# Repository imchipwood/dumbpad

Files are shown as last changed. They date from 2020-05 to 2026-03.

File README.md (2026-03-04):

 <a href="http://www.amitmerchant.com/electron-markdownify">dumbpad logo</a>

dumbpad is a simple macropad with support for up to two rotary encoders, designed to use [QMK](https://qmk.fm/) firmware.

## Gallery

v0.2 and v0.7 revisions in various layouts

Top two boards are v0.2, bottom two are v0.7. Bottom right is v0.7 with components soldered to the bottom, moving the rotary encoder to the right side.

## In this repository

This repo is separated into five main folders:

- [combo](./combo) houses the main PCB design which includes support for up to two rotary encoders and three status LEDs intended for the Pro Micro.
- [combo_oled](./combo_oled) was created by [KEEBD](https://keebd.com) and replaces the layer LED/Resistors with OLED display support and converted to KiCad.
- [combo_oled_low_profile](./combo_low_profile_oled) Revision of [combo_oled](./combo_oled) with low profile hot swap sockets for Gateron v2 switches
- [combo_teensy](./combo_teensy) is the same as [combo](./combo) but designed for the Teensy2.0.
- [reversible](./reversible) is an older, single-encoder revision using custom reversible Cherry MX sockets to allow the rotary encoder to be moved to the right side.
- [hotswap_rgb - v3.x](./hotswap_rgb) dumbpad featuring per-key RGB and Hotswap sockets

Each folder includes the Eagle or KiCad files as well as exported Gerber files for manufacturing. These folders also include readmes specific to those designs - check them for more info.

## Getting Started
To build your own dumbpad you will need to follow a couple of steps to get started. Described below are the minimal steps you will need to take to to assemble one dumbpad but every board configuration might require different steps. 
#### 1. Choose version. 
You can choose from one of the five different versions shown in the step above.
#### 2. Order your parts. 
Every board needs at least the following components but check the right folder for your parts list.
* 1 x PCB
* 16 x MX-style mechanical switches
* 17 x 1n4148 diodes (thru hole)
* 1 x Arduino Pro Micro or pin-compatible ATmega32u4-based MCU (Or teensy for the teensy version)
* (optional) 1 x EC11 rotary encoder with pushbutton (7-pin)
* (optional) 1 x 6mm tactile switch (to reset MCU)
* LEDS and OLED required for different configurations

#### 3. Assemble your dumbpad
For this step you will need a minimum of a soldering iron and a pair of tweezers
- Solder the diodes, switches, and Arduino Pro Micro (Or teensy) to the PCB

#### 4. Flash your firmware
You can use QMK to create and flash firmware to your dumbpad. You can configure every key to you can use the QMK configurator. Head over to the [QMK configurator](https://config.qmk.fm/#/friedrich/LAYOUT) and select dumbpad/[your version]. Once you have configured your board, click on compile and then on firmware to download the firmware. Check [qmk_firmware/keyboards/dumbpad](https://github.com/qmk/qmk_firmware/tree/master/keyboards/dumbpad) for compiling & uploading instructions

Once you have downloaded a .HEX firmware file we can head over to the [QMK toolbox](https://github.com/qmk/qmk_toolbox/releases) and flash the firmware. Plug in your dumbpad to your computer and set your QMK toolbox to ATmega32U4 for most Arduino Pro Micros. You will need to press your 6mm tacticle switch twice to enter the bootloader, wait for your computer to reconize the dumbpad and click on flash.

### Features

#### Status Indicator LEDs

All PCB revisions in this branch support up to three LEDs.

| LED position on PCB | LED name in QMK software | LED default behavior |
|:-:|:-:|:-:|
| right | LED_00 | 1s bit in binary layer indication |
| center | LED_01 | 2s bit in binary layer indication |
| left | LED_02 | numlock indicator |

LED_00 (right) and LED_01 (center) indicate the layer by displaying the layer number in binary:

| center LED | right LED  | layer |
|:---:|:---:|:---:|
| off | off | 0 (main) |
| off |  on | 1 |
|  on | off | 2 |
|  on |  on | 3 |

LED behavior can be changed in the QMK software if you'd like them to do something else. See [v1x.c](https://github.com/imchipwood/qmk_firmware/blob/dumbpad_refactor/keyboards/dumbpad/v1x/v1x.c) for reference.

#### (Optional) Reset Button

[combo](./combo), [hotswap_rgb](./hotswap_rgb) and [reversible](./reversible) have a 6mm switch socket that is optional to include when building your dumbpad. This socket shorts RST to GND to make it easy to enter the bootloader. This is not included in the [combo_teensy](./combo_teensy) design as the Teensy has a reset button already.

If you don't want to solder this switch, make sure to include the [RESET](https://docs.qmk.fm/#/quantum_keycodes) keycode somewhere in your keymap. If you don't include this keycode, you can still enter the bootloader by shorting RST to GND while plugging in the USB cable.

## PCB Dimensions and Cases

97mm x 78.5mm rectangle, with chamfered corners (chamfered edge is 2.828mm long).

There are several cases available for printing, some can be found in `./case`. Another nice case was designed by [f00k3r](https://twitter.com/f00k3r) and uploadead to printables: [Dumbpad Hotswap Case](https://www.printables.com/model/200528-dumbpad-hotswap-case).

### Mounting holes

There are four 2mm holes in a 40mm square centered at (x, y) 58.575mm, 39.425mm. These holes are not plated.

Mounting hole coordinates:

| x (mm) | y (mm) |
|:---:|:---:|
| 38.575 | 19.425 |
| 38.575 | 59.425 |
| 78.575 | 19.425 |
| 78.575 | 59.425 |

## Notes

- In particular, clickable rotary encoders take significantly more force to click than a keyboard switch, so place a rubber foot directly under or at least near any encoders

## Making the PCB

Every parts list includes at least one PCB. You can order a PCb yourself by different manufactures like; [PCB way](https://www.pcbway.com/) or [JLC Pcb](https://jlcpcb.com/) Submit one of the gerber zips from the folder of the type of board you want to make to your preferred manufacturer (or the Eagle .brd file if supported).

render of boards

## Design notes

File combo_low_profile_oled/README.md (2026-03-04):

# dumbpad - Low Profile OLED (aka v1.3)

Modified by [ReyvanZA]

## Description

Version of the original dumbpad but with support for an OLED display by Keebd, now with gateron low profile hot swap sockets.
There are also mounting points for a uController cover, and through holes for wires if using a ProMicro nrf52840 for the battery wires (admittedly not overly practical).

Only 1.3.1 has been tested with the gateron low profile hot-swap sockets. The gerber files included (see manufacturing notes at the end)

### Revisions

- 1.2 Keebd OLED with resistors
- 1.3.1 Gateron low profile hot-swap sockets (Confirmed working - need low profile keys to test)
- 1.3.2 (Untested) Combined plated though holes for EC11 rotary encoder mounting points and socket, added mounting holes for uController cover. Placed resistors on back of PCB so I can use an alignment plate for the switches to hold them more steadily.

### References

- Gateron low profile hot-swap sockets: https://gist.github.com/niw/22c68c2d7c869b990588b4875a654442

#### dumbpad v1.3.1

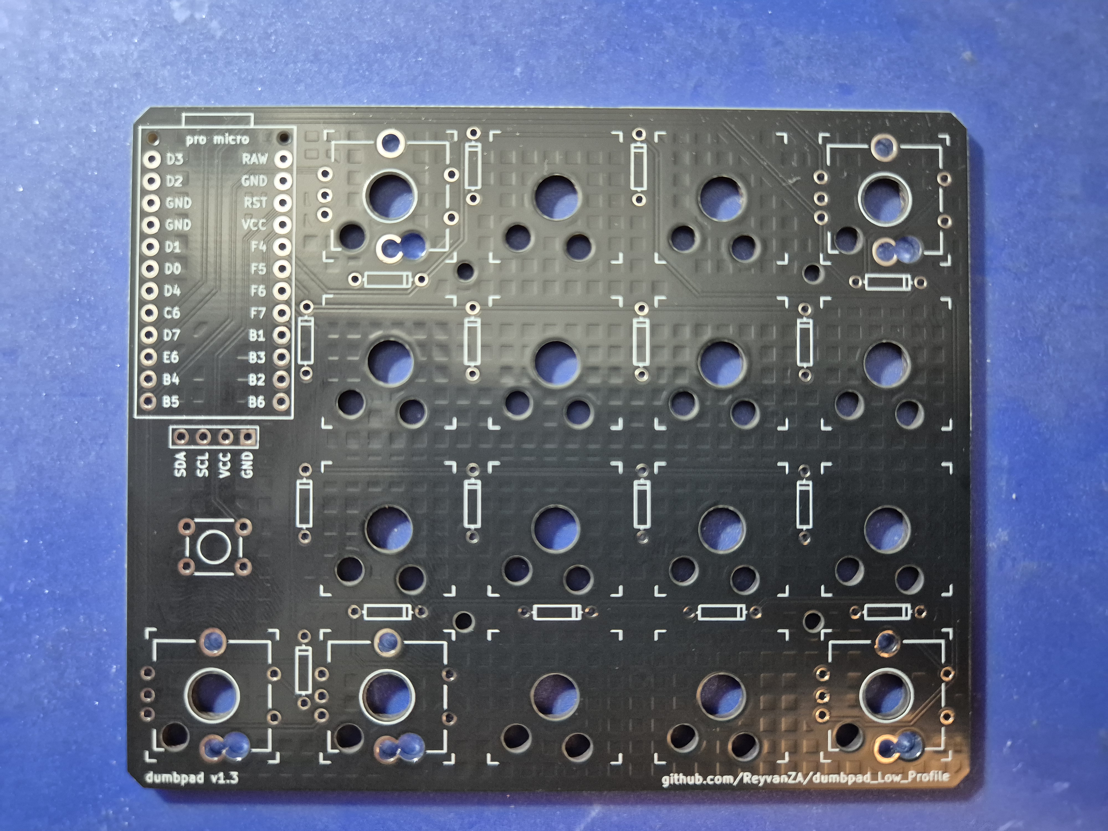
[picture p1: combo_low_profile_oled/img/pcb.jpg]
pcbs

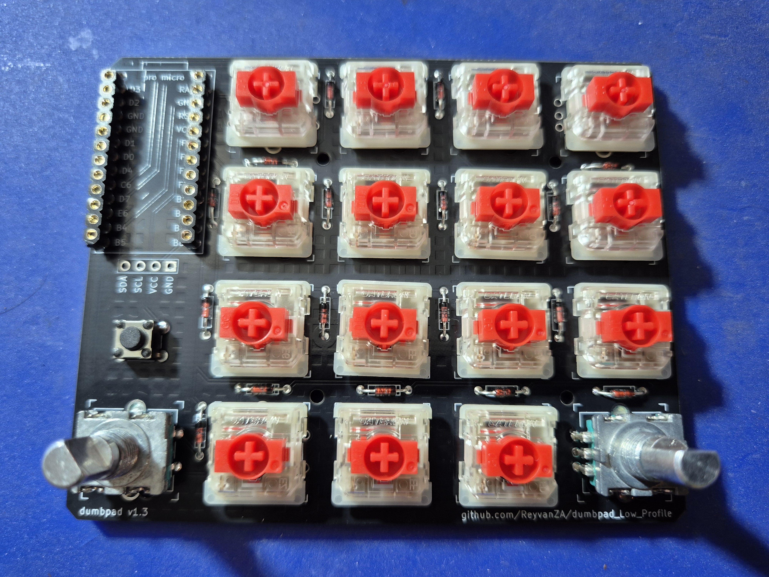
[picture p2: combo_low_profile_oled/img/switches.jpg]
finished

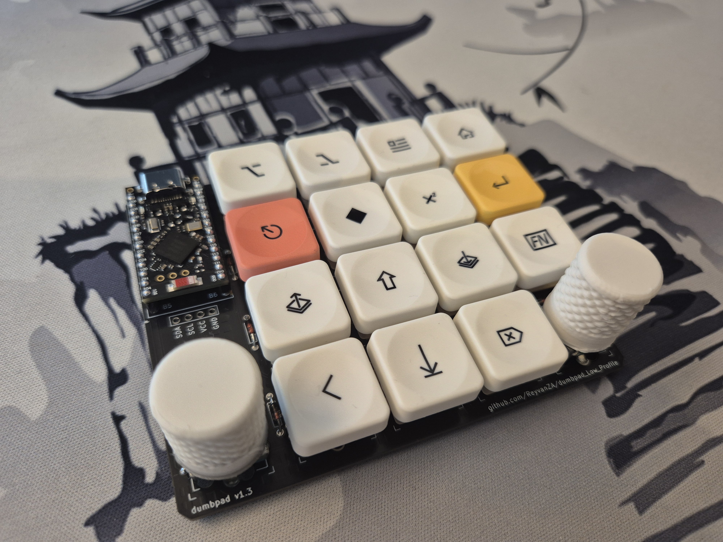
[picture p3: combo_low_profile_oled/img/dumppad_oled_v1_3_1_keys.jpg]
Keys1

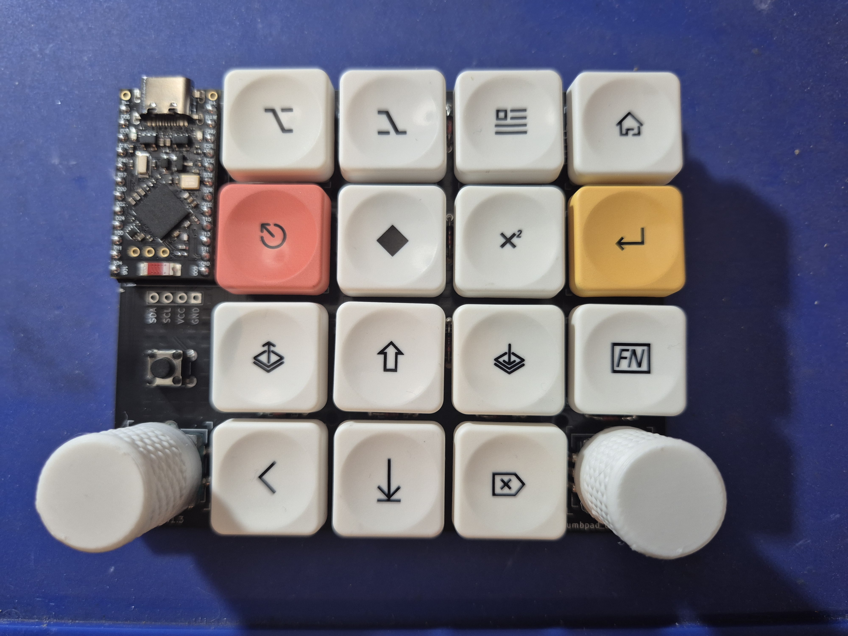
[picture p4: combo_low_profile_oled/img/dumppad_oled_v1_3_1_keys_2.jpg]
keys2


#### Renders (Latest Revision)

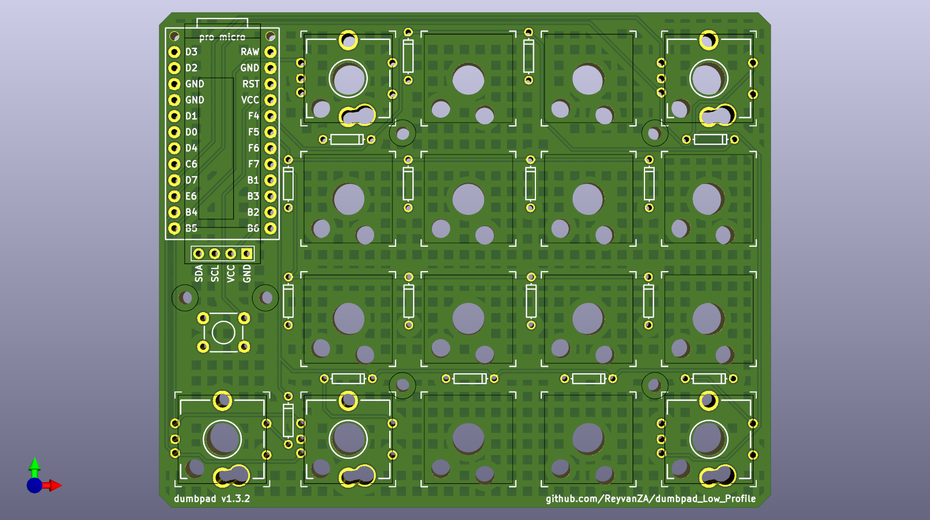
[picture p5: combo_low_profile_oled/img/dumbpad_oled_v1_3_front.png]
front

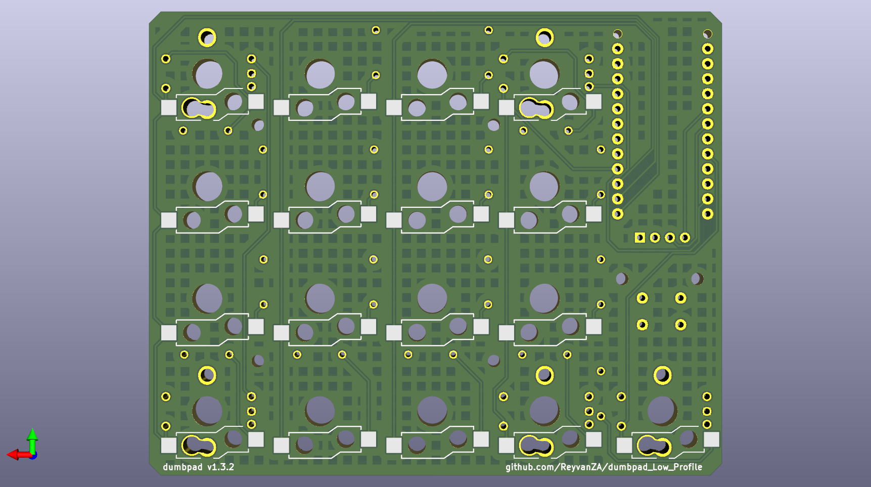
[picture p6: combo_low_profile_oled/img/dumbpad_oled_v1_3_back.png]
back


### Bill of materials
- 1 x PCB
- 16 x Gateron low profile switches (Link)
- 16 x Gateron low profile hot-swap sockets (Link)
- X x Keycaps (compatible with Gateron low profile switches)
- 17 x 1n4148 diodes (thru hole)
- 1 x Arduino Pro Micro or pin-compatible ATmega32u4-based MCU (Or teensy for the teensy version)
- 1 x or 2x EC11 rotary encoder with pushbutton (7-pin)
- 1 x 6mm tactile switch (to reset MCU)
- 1 x 0.91" 128X32 OLED Display (Optional)

## OLED Firmware

The OLED firmware is different and can be found here [Firmware](https://docs.keebd.com/firmware/)

## How to build 
- Be very careful when soldering pads next to rotary encoder through holes (encoder pin b), you may get bridging.
- I've moved the pin slightly closer to the ground pin to aleviate this issue. This does not affect assembly.

You can follow the instructions from the main [readme](https://github.com/imchipwood/dumbpad#getting-started) or follow the instruction in this [blog](https://www.timowielink.com/post/how-to-build-a-macropad) from [Timo Wielink](https://github.com/TimoWielink)

When the 1.3.1 production file is created by your PCB manufacturer, you may have a query on the overlapping through holes. If given the option allow them to plate both holes.

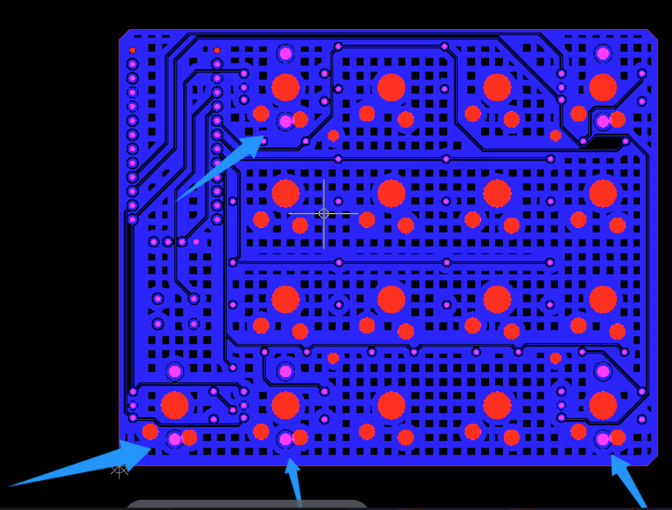
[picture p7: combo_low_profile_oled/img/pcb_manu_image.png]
Manufacturer


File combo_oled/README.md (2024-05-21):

# dumbpad - OLED (aka v1.2)

Designed by [KEEBD](https://www.keebd.com).

## Description

Version of the original dumbpad but with support for an OLED display in place of the LED's and resistors.
The EC11 rotary encoder-compatible slots have a non-plated through-punch for their mounting point on each side, which may be flagged as erronious by PCB manufacturers but has no effect on functionality.

### Revisions

- 1.2 Initial published PCB

#### dumbpad v1.2

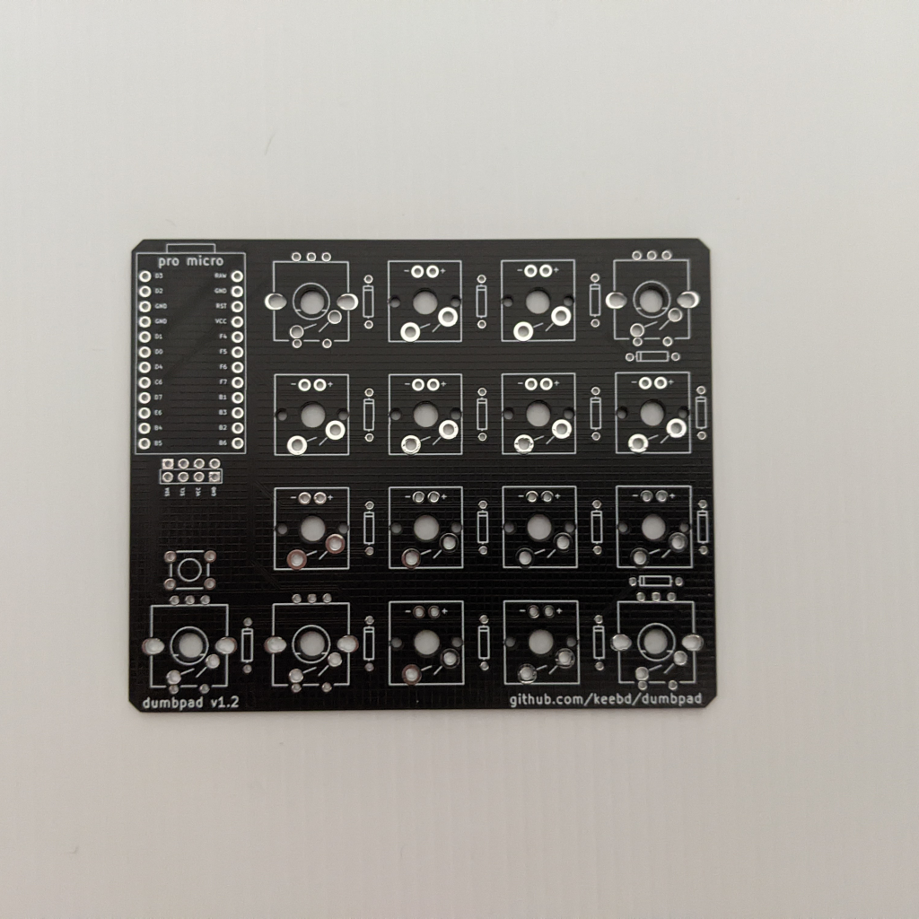
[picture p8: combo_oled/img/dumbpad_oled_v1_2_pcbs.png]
pcbs

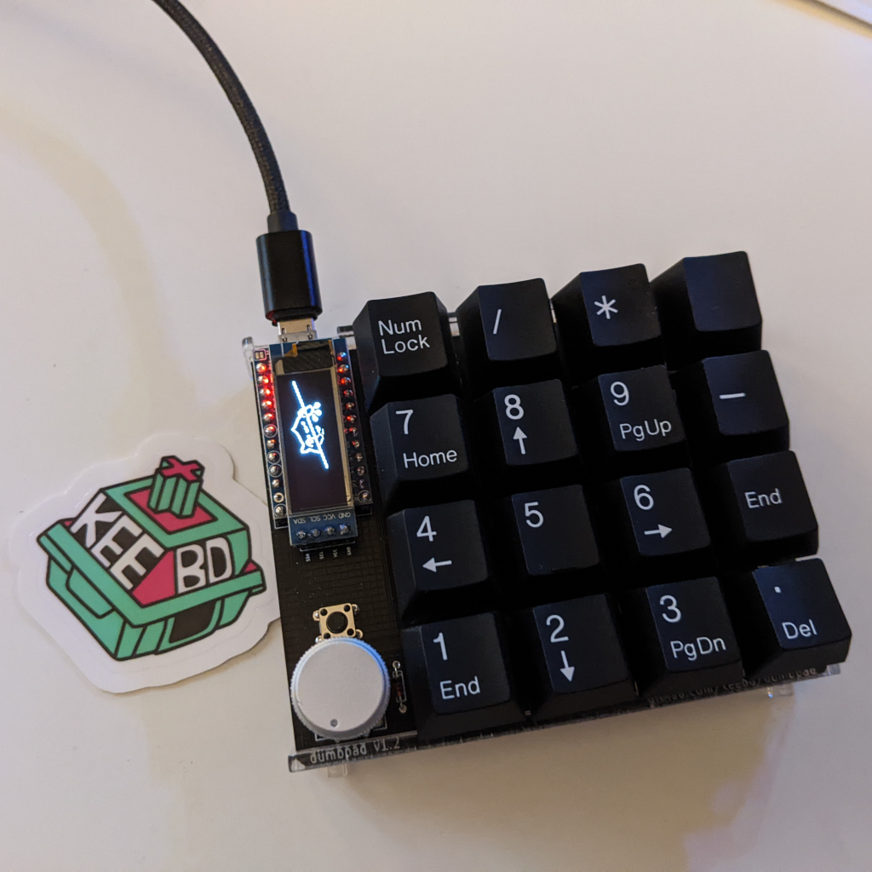
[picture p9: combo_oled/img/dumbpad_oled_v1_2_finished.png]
finished


#### Renders

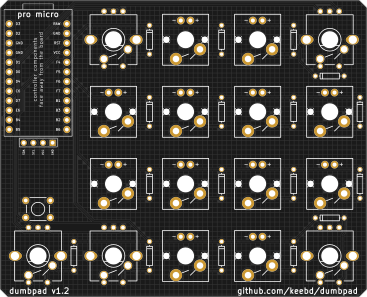
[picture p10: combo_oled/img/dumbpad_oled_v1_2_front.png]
front

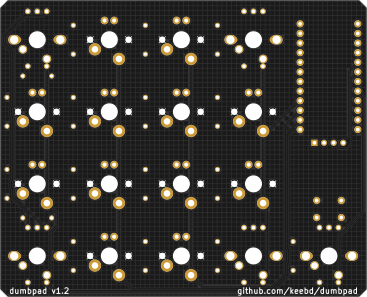
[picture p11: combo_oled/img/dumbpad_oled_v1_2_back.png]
back


### Bill of materials
- 1 x PCB
- 16 x MX-style mechanical switches
- 17 x 1n4148 diodes (thru hole)
- 1 x Arduino Pro Micro or pin-compatible ATmega32u4-based MCU (Or teensy for the teensy version)
- 1 x or 2x EC11 rotary encoder with pushbutton (7-pin)
- 1 x 6mm tactile switch (to reset MCU)
- 1 x 0.91" 128X32 OLED Display

## OLED Firmware

The OLED firmware is different and can be found here [Firmware](https://docs.keebd.com/firmware/)

## How to build 
You can follow the instreuctions from the main [readme](https://github.com/imchipwood/dumbpad#getting-started) or follow the instructiosn in this [blog](https://www.timowielink.com/post/how-to-build-a-macropad) from [Timo Wielink](https://github.com/TimoWielink)

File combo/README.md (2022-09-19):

# dumbpad/combo

This folder houses the dumbpad "combo" design - this layout uses custom "combo" Cherry MX + EC11 rotary encoder sockets that allow a single PCB design to support both single- and dual-encoder layouts.

## Compiling QMK

The [QMK Configurator](https://config.qmk.fm/#/dumbpad/v1x/LAYOUT) can compile the various dumbpad versions
with basic rotary encoder support. The default rotary encoder actions are as follows:

| Layer | Clockwise | Counter-clockwise |
|:-:|:-:|:-:|
| 1 | KC_MS_R (move mouse right) | KC_MS_L (move mouse left) |
| 2 | KC_EQUALS (Adobe "increase") | KC_MINUS (Adobe "decrease") |

If you want the encoder to do something else, you will need to clone the [qmk_firmare](https://github.com/qmk/qmk_firmware) repository and modify the rotary encoder code. The [QMK docs](https://docs.qmk.fm/#/newbs) can help you with this.

## Eagle PCB render

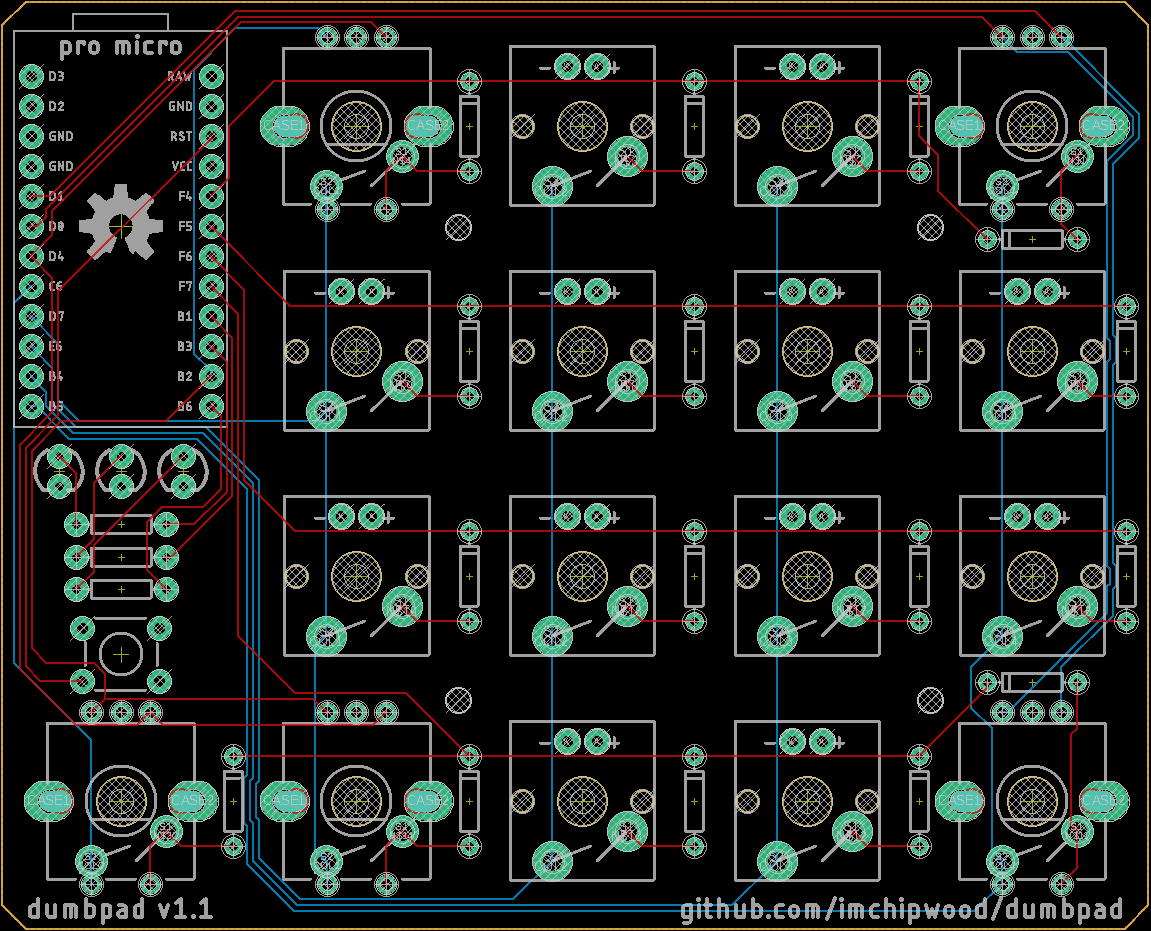
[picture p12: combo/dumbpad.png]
dumbpad


## Case

A case is available on [Thingiverse](https://www.thingiverse.com/thing:4816409) - thanks to Anthony @ [customkbd.com](http://customkbd.com.au/) for the initial design and being kind enough to send the original design files!

## Single- vs Dual-Encoder Support

The combined Cherry MX/encoder sockets allow single- and dual-encoder configurations.

The only rule when using two encoders is that there cannot be two encoders on the left side at once, or two on the right side.
This table shows where the encoders are in the switch grid ("X" for encoder, "s" for switch):

| C0  | C1  | C2  | C3  | C4  |
|:---:|:---:|:---:|:---:|:---:|
| |__X__|  s  |  s  |__X__|
| |  s  |  s  |  s  |  s  |
| |  s  |  s  |  s  |  s  |
|__X__|__X__|  s  |  s  |__X__|

- The three encoders in columns C0 and C1 are connected to each other
- The two encoders in column C4 are connected to each other

So, if doing dual encoders, one must be in column C4 and the other in either C0 or C1. Three or more encoders will not work.

The following sections describe the configurations that the default keymaps in QMK are designed for.

### Single-Encoder (Default Configuration)

In the default configuration, the encoder is in column 0, the bottom left corner below the Pro Micro. All other sockets are filled with switches.

| C0  | C1  | C2  | C3  | C4  |
|:---:|:---:|:---:|:---:|:---:|
| |  s  |  s  |  s  |  s  |
| |  s  |  s  |  s  |  s  |
| |  s  |  s  |  s  |  s  |
|__X__|  s  |  s  |  s  |  s  |

single encoder

### Dual-Encoder Bottom

One dual-encoder configuration has encoders in the bottom two corners of the 4x4 grid, and switches in the rest of the grid. The socket in column 0 is left empty.

| C0  | C1  | C2  | C3  | C4  |
|:---:|:---:|:---:|:---:|:---:|
| |  s  |  s  |  s  |  s  |
| |  s  |  s  |  s  |  s  |
| |  s  |  s  |  s  |  s  |
| |__X__|  s  |  s  |__X__|

dual-encoder bottom

### Dual-Encoder Top

Another dual-encoder configuration has encoders in the top two corners of the 4x4 grid, and switches in the rest of the grid. The socket in column 0 is left empty.

| C0  | C1  | C2  | C3  | C4  |
|:---:|:---:|:---:|:---:|:---:|
| |__X__|  s  |  s  |__X__|
| |  s  |  s  |  s  |  s  |
| |  s  |  s  |  s  |  s  |
| |  s  |  s  |  s  |  s  |

dual-encoder top

### No-Encoder

You may also choose not to use any rotary encoders if you like!

### Bill Of Materials

- 1 x PCB
- 16 x MX-style mechanical switches
- 17 x 1n4148 diodes (thru hole)
- 1 x Arduino Pro Micro or pin-compatible ATmega32u4-based MCU (Or teensy for the teensy version)
- 1x or 2x EC11 rotary encoder with pushbutton (7-pin)
- (optional) 1 x 6mm tactile switch (to reset MCU)
- (optional) 3x 3mm resistors (for limiting current in LEDs)

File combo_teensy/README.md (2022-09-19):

# dumbpad/combo_teensy

This folder houses the dumbpad "combo_teensy" design - this layout uses custom "combo" Cherry MX + EC11 rotary encoder sockets that allow a single PCB design to support both single- and dual-encoder layouts. It uses Teensy2.0 microcontroller instead of a Pro Micro

## Eagle PCB render

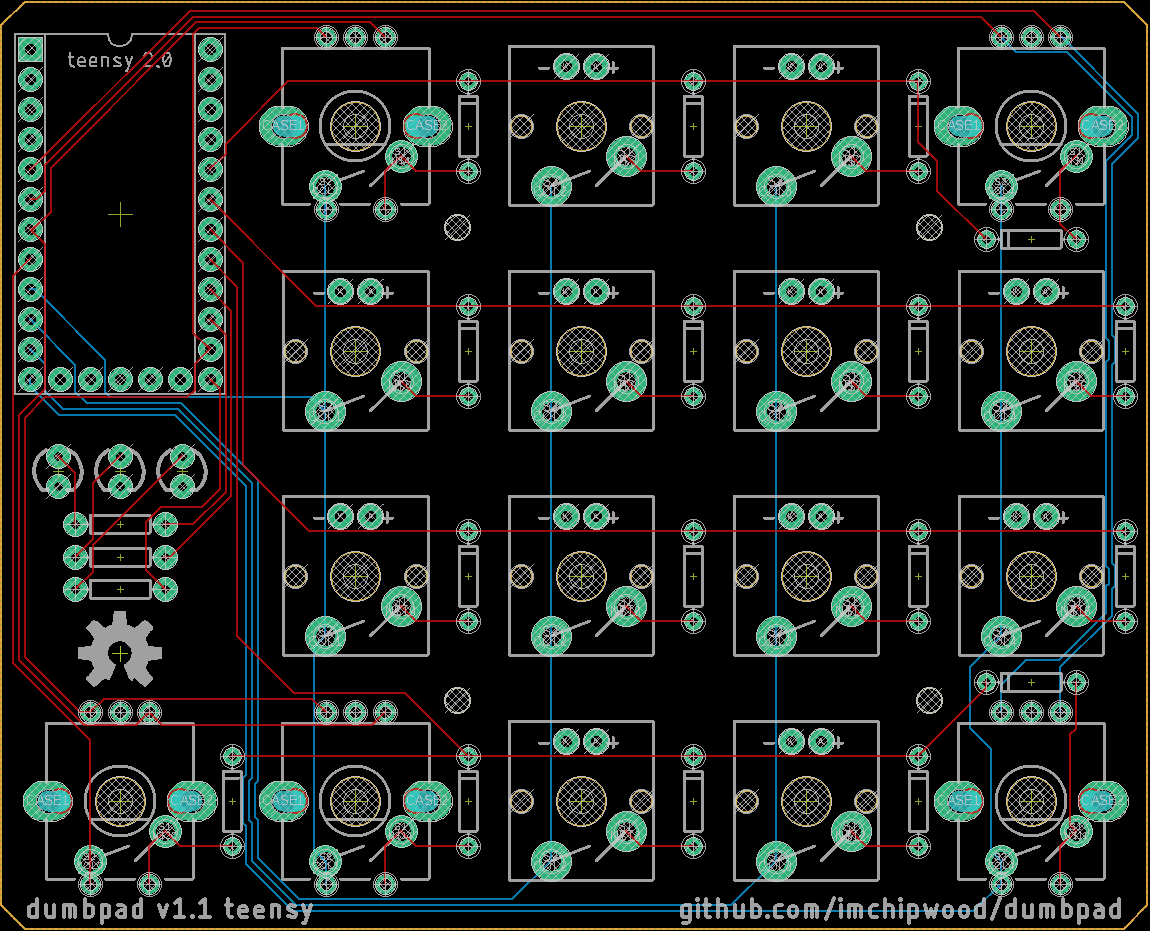
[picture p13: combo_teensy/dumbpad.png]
dumbpad


## Single- vs Dual-Encoder Support

The combined Cherry MX/encoder sockets allow single- and dual-encoder configurations.

The only rule when using two encoders is that there cannot be two encoders on the left side at once, or two on the right side.
This table shows where the encoders are in the switch grid ("X" for encoder, "s" for switch):

| C0  | C1  | C2  | C3  | C4  |
|:---:|:---:|:---:|:---:|:---:|
| |__X__|  s  |  s  |__X__|
| |  s  |  s  |  s  |  s  |
| |  s  |  s  |  s  |  s  |
|__X__|__X__|  s  |  s  |__X__|

- The three encoders in columns C0 and C1 are connected to each other
- The two encoders in column C4 are connected to each other

So, if doing dual encoders, one must be in column C4 and the other in either C0 or C1. Three or more encoders will not work.

The following sections describe the configurations that the default keymaps in QMK are designed for.

### Single-Encoder (Default Configuration)

In the default configuration, the encoder is in column 0, the bottom left corner below the Pro Micro. All other sockets are filled with switches.

| C0  | C1  | C2  | C3  | C4  |
|:---:|:---:|:---:|:---:|:---:|
| |  s  |  s  |  s  |  s  |
| |  s  |  s  |  s  |  s  |
| |  s  |  s  |  s  |  s  |
|__X__|  s  |  s  |  s  |  s  |

### Dual-Encoder Bottom

One dual-encoder configuration has encoders in the bottom two corners of the 4x4 grid, and switches in the rest of the grid. The socket in column 0 is left empty.

| C0  | C1  | C2  | C3  | C4  |
|:---:|:---:|:---:|:---:|:---:|
| |  s  |  s  |  s  |  s  |
| |  s  |  s  |  s  |  s  |
| |  s  |  s  |  s  |  s  |
| |__X__|  s  |  s  |__X__|

### Dual-Encoder Top

Another dual-encoder configuration has encoders in the top two corners of the 4x4 grid, and switches in the rest of the grid. The socket in column 0 is left empty.

| C0  | C1  | C2  | C3  | C4  |
|:---:|:---:|:---:|:---:|:---:|
| |__X__|  s  |  s  |__X__|
| |  s  |  s  |  s  |  s  |
| |  s  |  s  |  s  |  s  |
| |  s  |  s  |  s  |  s  |

### No-Encoder

You may also choose not to use any rotary encoders if you like!

### Bill Of Materials

1 x PCB
16 x MX-style mechanical switches
17 x 1n4148 diodes (thru hole)
1 x Teensy2.0 
1 x or 2 x EC11 rotary encoder with pushbutton (7-pin)
- (optional) 3x 3mm LEDs
- (optional) 3x 3mm resistors (for limiting current in LEDs)
- (optional) 6mm SPST switch for resetting MCU

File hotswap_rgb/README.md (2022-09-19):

# dumbpad - Hotswap - RGB (aka v3x)

Designed by [deveth0](https://www.github.com/deveth0).

## Description

Version of the original dumbpad that features Kailh Hotswap Sockets and (optional) RGB per-key lightning.

### Revisions

- 3.1 Initial published PCB

#### dumbpad v3.1

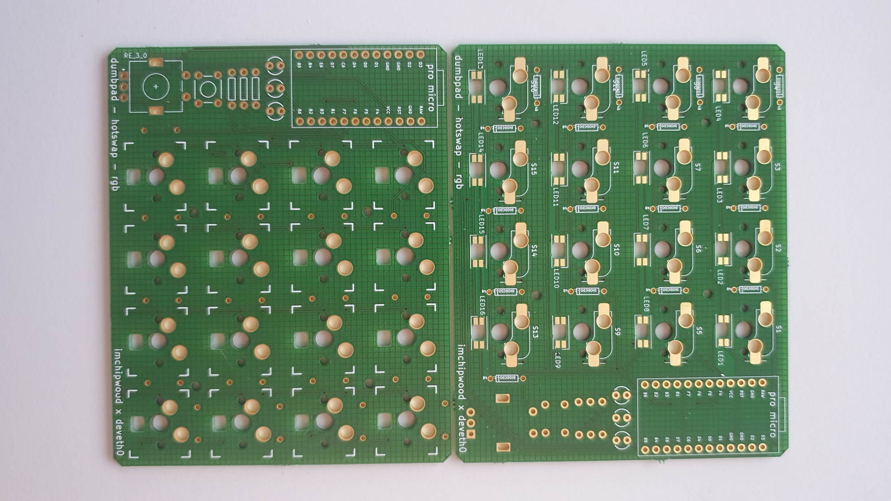
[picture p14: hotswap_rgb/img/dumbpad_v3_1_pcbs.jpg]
pcbs

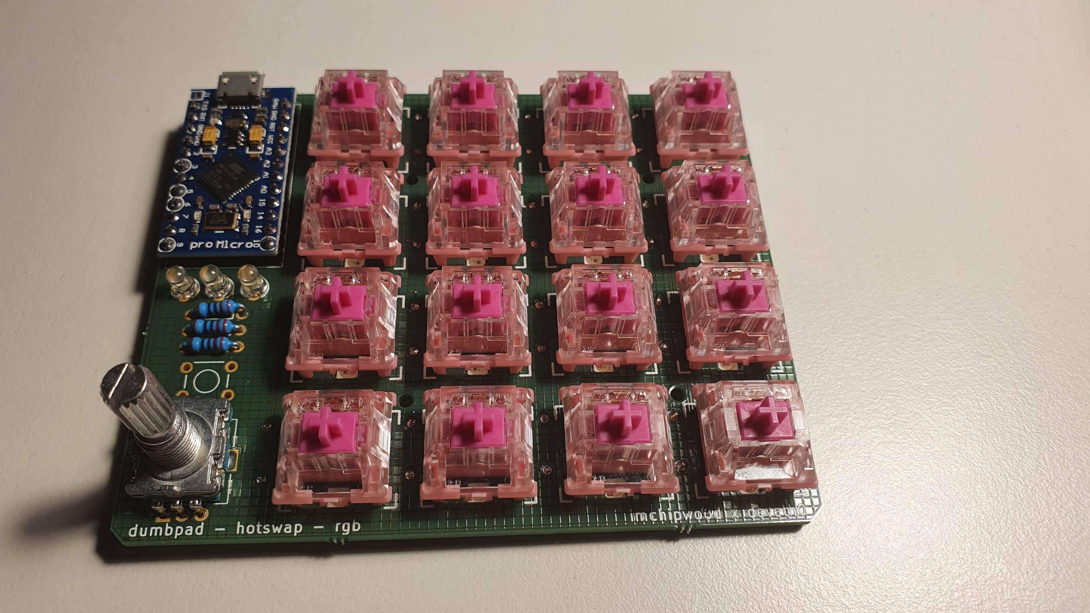
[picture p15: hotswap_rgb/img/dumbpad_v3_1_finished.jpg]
finished


#### Renders
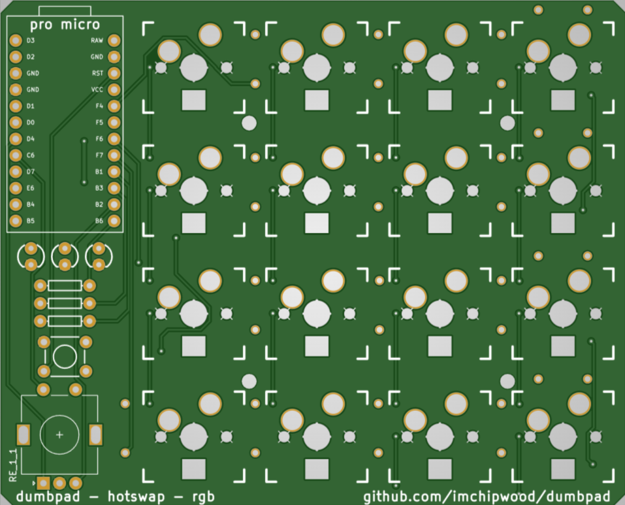
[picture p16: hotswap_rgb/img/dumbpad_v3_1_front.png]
front


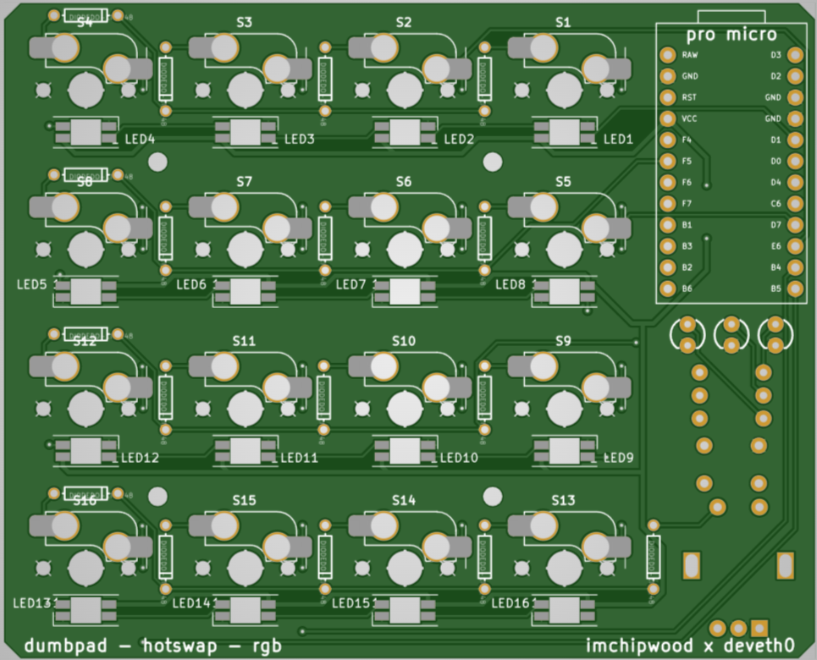
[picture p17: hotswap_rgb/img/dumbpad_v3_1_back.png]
back


### Bill of materials

* 16x Kailh Hotswap Sockets (rev 2)
* 16x Cherry-style mechanical switches
* 17x 1n4148 diodes (thru hole)
* 1x Arduino Pro Micro or pin-compatible ATmega32u4-based MCU
* 1x EC11 rotary encoder with pushbutton (7-pin)
* (optional) 16x SK6812 mini e LEDs
* (optional) 1x 6mm tactile switch (to reset MCU)
* (optional) 3x 3mm LEDs (whatever color)
* (optional) 3x 330ohm or similar resistors for the LEDS (not needed if not adding LEDs)

## Making the PCB

Submit either the KiCad `.kicad_pcb` or the gerber files to your prefered PCB manufacturer.

### Notes on soldering

It's recommended to start with the Sockets and then add the remaining parts.

Solder the SK6812 LEDs with the missing corners aligned with the corners printed on the PCB as shown in the image.

*NOTE:* the orientation of the LEDs changes between the lines!

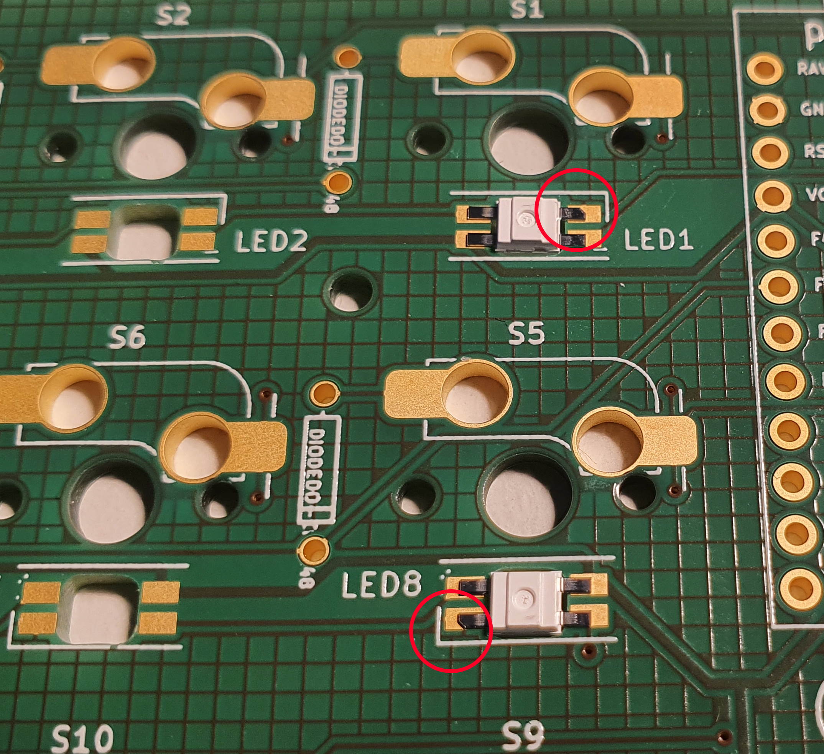
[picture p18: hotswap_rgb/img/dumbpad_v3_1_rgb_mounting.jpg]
rgb


## Acknowledgements

Some of the footprints are extracted from the awesome [Corne Keyboard](https://github.com/foostan/crkbd) by [Kosuke Adachi](https://github.com/foostan).

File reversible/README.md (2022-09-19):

# dumbpad
Designed by [imchipwood](https://www.github.com/imchipwood) in Portland, Oregon, USA

Special thanks to [QMK](https://qmk.fm/) for open-source keyboard firmware

## Description
dumbpad is a simple 4x4 numpad with a rotary encoder. It is designed for the ATmega32u4-based Pro Micro but any ATmega32u4-based microcontroller using the same form factor should work

It is designed to run [QMK firmware](https://github.com/qmk/qmk_firmware) - check [qmk_firmware/keyboards/dumbpad](https://github.com/qmk/qmk_firmware/tree/master/keyboards/dumbpad) for compiling & uploading instructions

### Revisions
- v0.5 introduces 2x LEDs for indicating which layer is enabled, accurately representing up to 4 layers
- v0.6_dualencoder is a true 4x4 macropad with two rotary encoders - one in each bottom corner
- v0.6_dualencoder_top is the same as v0.6_dualencoder but the encoders are moved to the top corners
- v0.7 PCB is flippable. Two jumpers must be soldered:
  - Encoder on left (default layout) - solder the left side of the jumpers to the center
  - Encoder on right (PCB upside down) - solder the right side of the jumpers to the center
- v1.0 PCB adds a 3rd LED - default use is to indicate if NUMLOCK is on

#### dumbpad v0.2 (top) & v0.7 (bottom), PCB by [OSH Park](https://www.oshpark.com)
dumbpad
#### Dual-encoder version by chicocode:
dumbpad
#### Eagle PCB render
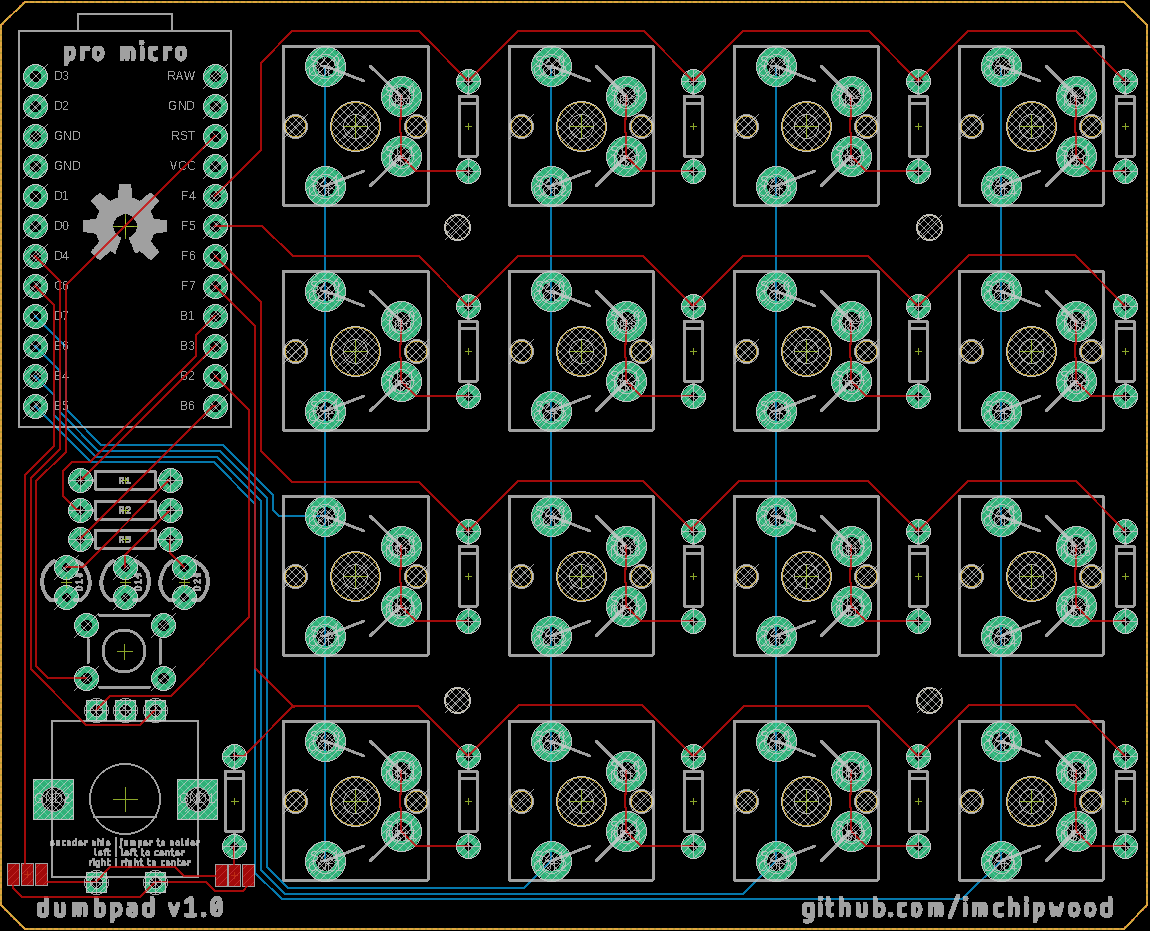
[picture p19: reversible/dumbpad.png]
dumbpad


### Bill of materials
* 16x Cherry-style mechanical switches
* 17x 1n4148 diodes (thru hole)
* 1x Arduino Pro Micro or pin-compatible ATmega32u4-based MCU
* 1x EC11 rotary encoder with pushbutton (7-pin)
* (optional) 1x 6mm tactile switch (to reset MCU)
* (optional) 3x 3mm LEDs (whatever color)
* (optional) 3x 330ohm or similar resistors for the LEDS (not needed if not adding LEDs)

#### Notes
- No case is currently available, but v1.0 has 2mm mounting holes in a 40mm square centered at x=58.575mm, y=39.425mm (from the bottom left)
  - 38.575, 19.425
  - 38.575, 59.425
  - 78.575, 19.425
  - 78.575, 59.425
- To avoid damaging the PCB and prevent it from sliding around, put rubber feet on the bottom of the PCB
  - place feet directly under the rotary encoder(s) as they take significant force to press
  - place the others in the corners and one in the center

## Making the PCB
Submit the `.brd` file to your preferred PCB manufacturer - be mindful of minimum quantity requirements.

### OSH Park - USA PCB Manufacturing
Shameless Portland, Oregon company plug - [OSH Park](https://www.oshpark.com) is a fast and reliable manufacturer, combining multiple individual orders into a single panel to minimize end-user costs. dumbpad is just under $60 for 3 copies through OSH Park.

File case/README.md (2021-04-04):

# Dumbpad Case

based off the original design by Anthony @ [customkbd.com.au](https://customkbd.com/collections/cases/products/dumbpad-3d-printed-highcase) - huge thanks to him for his initial work and sending me the STL files I used to create a batch through Shapeways

Files also available on [Thingiverse](https://www.thingiverse.com/thing:4816442)

## Changes from Anthony's design

Main difference is some tabs added in the corners to support the PCB a little better.

I found the original design flexed quite a bit, especially when pressing the rotary encoder. This design aims to fix that.

Also removed some material under the Pro Micro USB port to prevent stress on the port if the Pro Micro is soldered directly to the PCB.

## Redesigned using SketchUp because

1. I suck at any other 3d modeling software
1. I've used it before
1. It was literally quicker to redraw the whole thing in SketchUp than try to learn a new tool.

### dumbpad_case

Basic case.

### dumbpad_case_emboss

Same as dumbpad_case with "dumbpad" emboss on the rear face.

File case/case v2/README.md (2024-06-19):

# Printing Settings:
I use a Flying Bear Ghost 5 with a 0.4mm nozzle.

## File: dumbpad_lid.stl
Horizontal Hole Expansion:
Adjust the horizontal hole expansion parameter in Cura or a similar slicer. Recommended values range from -1.6 to -0.2.
## File: 6mm_split_shaft_pot_knob_12mm.stl
Horizontal Hole Expansion:
The required adjustment depends on the type of filament used to ensure a snug fit of the knob on the shaft without wobbling. Alternatively, a 6mm drill bit can be used for precise fitting.
## Mounting the PCB:
 Use 4 M2x5mm bolts to secure the PCB to the case. Alternatively, other bolt sizes can be used by adjusting the horizontal hole expansion settings accordingly.
## Additional Information
 All files were edited using KOMPAS-3D software, and the source files in .m3d format are also included.

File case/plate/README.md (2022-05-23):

## 3D-Printable Mounting Plate for dumbpad
Mounting plates designed for dumbpad v1.x ([dumbpad by imchipwood](https://github.com/imchipwood/dumbpad/)); fits in the case designed by Anthony @ [customkbd.com.au](https://customkbd.com.au/); 1.5mm thick.

I found out that the hot-swap sockets I soldered in cannot hold switches firmly enough, and plates were needed. Hence, I started this project.

Also available on [Thingiverse](https://www.thingiverse.com/thing:4971965)
<br/><br/>

### COMBOS
- 2 Rotary Encoders
  - [2 rotary encoders on top](2_top.stl)
  - [2 rotary encoders on bottom](2_bot.stl)
- 1 Rotary Encoders
  - [top left](top_left.stl)
  - [top right](top_right.stl)
  - [bot left](bot_left.stl)
  - [bot right](bot_right.stl)
- No Rotary Encoders/Default
  - [full plate](full_plate.stl)

*Note: The thinnest edge is the right edge, otherwise it won't fit into the case*

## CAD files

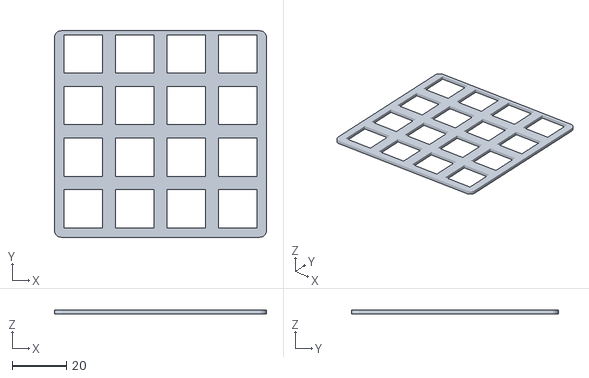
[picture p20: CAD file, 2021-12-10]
case/plate/full_plate.stl
78.4 x 76.4 x 1.50

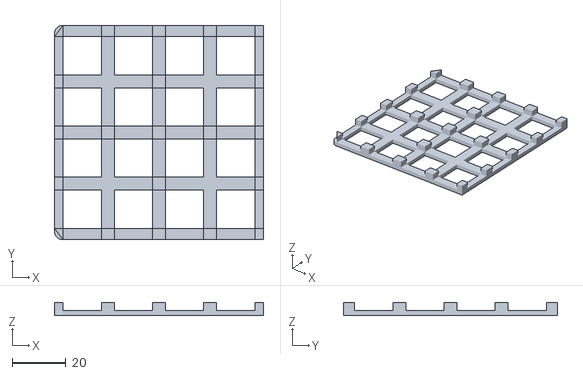
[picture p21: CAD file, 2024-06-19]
case/case v2/dumb_pleyt_v2.stl
77.8 x 79.8 x 5.00

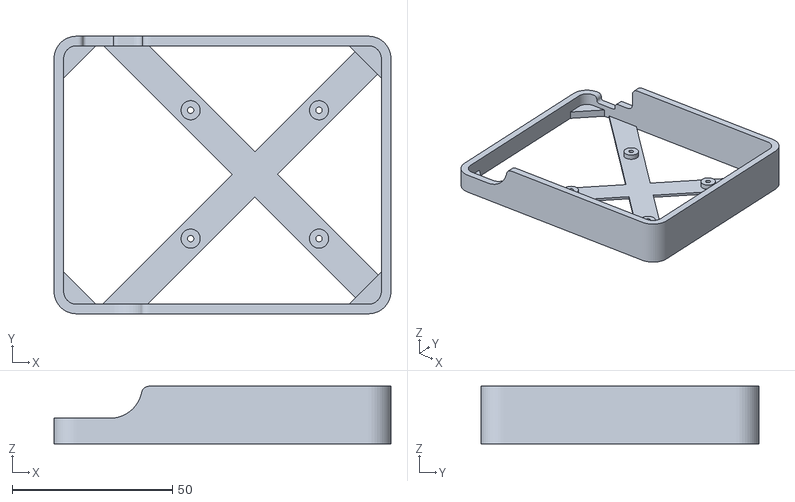
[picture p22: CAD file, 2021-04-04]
case/dumbpad_case.stl
105.0 x 86.5 x 18.0

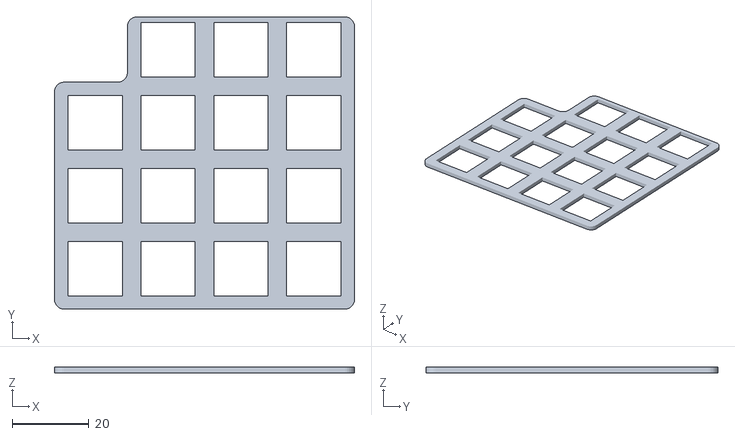
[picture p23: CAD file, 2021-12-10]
case/plate/top_right.stl
78.4 x 76.4 x 1.50

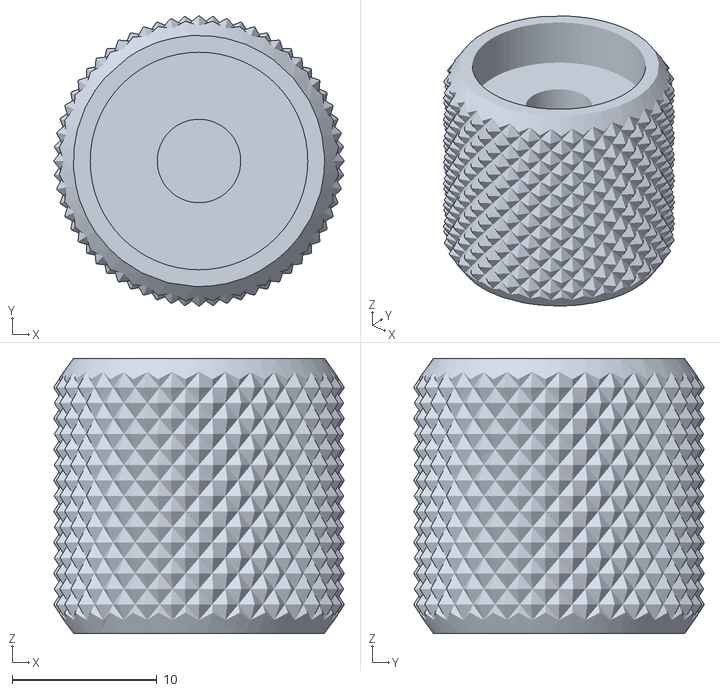
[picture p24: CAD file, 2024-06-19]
case/case v2/6mm_split_shaft_pot_knob_12mm.stl
20.0 x 20.0 x 19.0

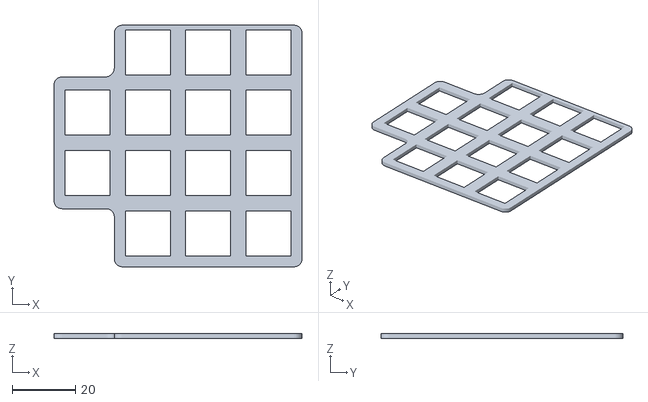
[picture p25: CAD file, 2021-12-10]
case/plate/2_top.stl
78.4 x 76.4 x 1.50

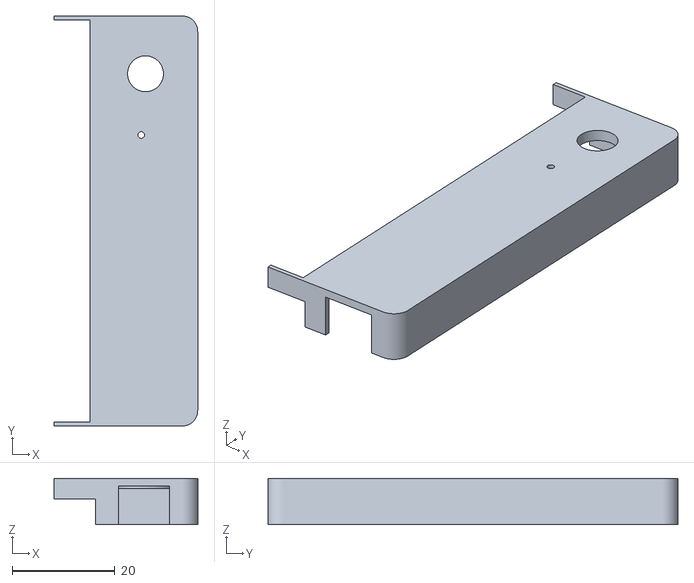
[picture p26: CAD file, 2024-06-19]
case/case v2/dumpad_lid.stl
28.0 x 80.0 x 9.00

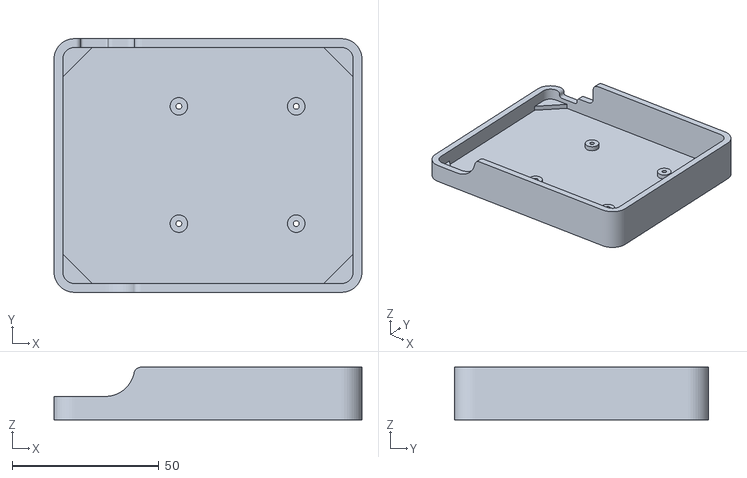
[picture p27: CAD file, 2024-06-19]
case/case v2/dumbpad_case_v2.stl
105.0 x 86.5 x 18.0

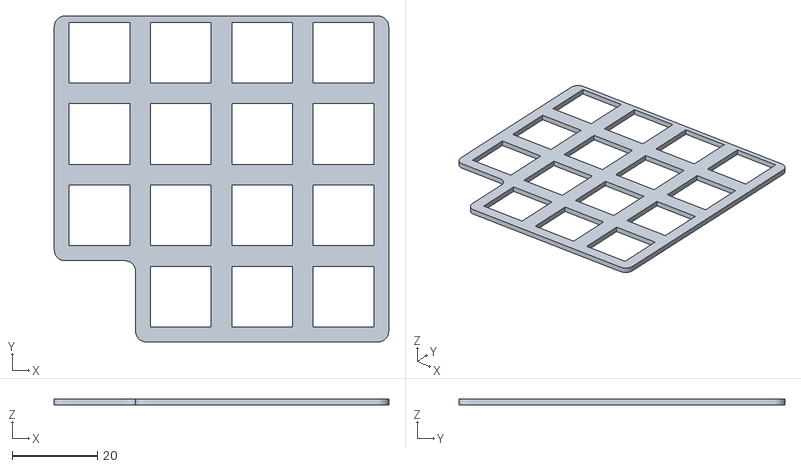
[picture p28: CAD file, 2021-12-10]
case/plate/top_left.stl
78.4 x 76.4 x 1.50

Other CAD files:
case/dumbpad_case_emboss.stl
case/plate/bot_right.stl
case/plate/2_bot.stl
case/plate/bot_left.stl
case/dumbpad_case.skp
case/dumbpad_case_emboss.skp

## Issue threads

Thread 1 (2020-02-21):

LED Question

revere521, 2020-02-21:
Hello sir - I was wondering if you could help me understand what code to modify in my keymap.c to change the behavior of one of the LEDs?

The LED that lights when the layer key is pressed (or toggled) works fine, but the other never illuminates.   I'd like to see if I could set it to light when i press the center button on the rotary encoder (currently set to mute on the main layer)

I see the section below in the keymap.c, but its not clear to me how to leverage it

```
void led_set_user(uint8_t usb_led) {
}
```

imchipwood, 2020-04-15:
Woah sorry I never saw this until now! I have not really tested the LED code - I only just ordered some new boards with the LED sockets last weekend, they haven't arrived yet.

If I wrote the code correctly, both LEDs should be used to indicate the layer in a binary fashion.

Assuming the right LED is the 1s position and the left LED is the 2s position, it should look like this
- layer 0: 00 (both LEDs off)
- layer 1: 01 (right LED on)
- layer 2: 10 (left LED on)
- layer 3: 11 (both LEDs on)

If you don't ever use layer 2 or higher, the left LED shouldn't turn on unless you add custom code to `led_set_user`

Look in `dumbpad.c` `layer_state_set_kb` to see how the LEDs are turned on/off - you can change what the LEDs do in your `led_set_user` function by calling `writePin` on the LED of interest (`LAYER_INDICATION_LED_0` or `LAYER_INDICATION_LED_0`) with a value of 0 (off) or 1 (on). How you decide when to turn an LED on or off is up to you.

revere521, 2020-04-15:
no worries at all.  I think i found this through trial and error - since I'm only using 1 layer, the second light has no function in the current code.

I also designed some 3d printed cases for your board if you are interested: https://www.thingiverse.com/thing:4175635

imchipwood, 2020-04-15:
Awesome, hope you found a use for that LED.

I'm closing this issue since you've got another one open about the case.

Closed 2020-04-15.

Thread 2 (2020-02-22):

Not An Issue - I Designed Some 3D Printable Cases if you are interested

revere521, 2020-02-22:
I designed these if you are interested - nice work by the way - the PCB's are great - I've had some fun with this

https://www.thingiverse.com/thing:4175635

imchipwood, 2020-04-15:
Wow, sorry I missed this! Not sure why I didn't get notified of the issue - will look into that...

These are super cool - I like that you wired the rotary encoder as an external component for use with that huge knob!

Do you mind if I the thingiverse link to the READMEs?

revere521, 2020-04-15:
I do not mind at all, please do!

I did make a smaller case too with the encoder on the board, but with the board still upside down.  The STEP files are there so it can be modified as a starting point fo rother configurations

Closed 2021-12-08.

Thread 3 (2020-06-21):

hi, i had an issue on the encoder and the third led

ryandiwdjj, 2020-06-21:
the default mapping on qmk_firmware, the rotary and the third LED doesn't work (im using the v1.1 board) but i already make the fix and if you want i can send my files. (sorry for my bad english as it is not my mother language)

imchipwood, 2020-06-22:
What branch did you use to build the qmk_firmware? The correct branch is `dumbpad_refactor` - maybe I forgot to push some code?

ryandiwdjj, 2020-06-23:
i dont see any branch named dumbpad_refactor

imchipwood, 2020-06-23:
OK, I see. You're talking about this repo and the Eagle files.

No update is need in this repository if you use the correct qmk_firmware branch.

I am using a v1.1 right now and it's working fine with the code in [imchipwood/qmk_firmware/tree/dumbpad_refactor](http://github.com/imchipwood/qmk_firmware/tree/dumbpad_refactor)

imchipwood, 2020-06-23:
The reason for this: v1.1 is significantly different from v1.0, in order to support both single- and dual-encoder layouts. The v1.1 layout uses the same encoder & LED pins as v0.6_dualencoder - the v1.1 design is actually based around the original dualencoder designs.

ryandiwdjj, 2020-06-23:
aahh i see, anyway i have already fix it by myself after i trace it one by one LOL, i just though maybe someone out there had the same issue as me, thanks for the reply though! the design sure is beautiful!

imchipwood, 2020-06-23:
Glad you like it, do you mind sending me a photo of yours? I like seeing what people have made :)

ryandiwdjj, 2020-06-24:
here's mine, i use the third LED as my third layer indicator lmao
https://imgur.com/1YVRIGx

imchipwood, 2020-06-24:
Awesome, I hadn't seen anyone put the encoders in opposite corners like that yet!

Thanks for the photo - do you mind if I include it in the v1.1 README?

ryandiwdjj, 2020-06-24:
yea i don't mind, hahahaha i think its kinda weird too but that is the most comfortable layout for me, also i'm going to try to make the acrylic case for it in free time, when its done i'm going to put the file in this issue

imchipwood, 2020-06-24:
I'd actually like to close this issue - feel free to submit another issue when you've made the case!

Closed 2020-06-24.

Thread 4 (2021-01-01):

Flash mode

shaye1444, 2021-01-01:
How would one go into flash mode to change firmware?

breakawayt, 2021-01-01:
> How would one go into flash mode to change firmware?

Two methods that i've discovered:
1. Double-press the switch button (top of rotary encoder, if you've got this soldered)
2. Hold down rotary encoder pushbutton while plugging in to enter bootloader (according to config.h)
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

imchipwood, 2021-01-04:
If you're simply looking to flash, you only have to press the reset button once. This resets the Arduino and will temporarily enter the bootloader during the normal boot sequence - if your computer is currently attempting to flash the board, it will detect this and flashing will begin. Double pressing the reset button will enter the bootloader for 8 seconds.

These methods will work if you've already flashed the Arduino with QMK once:
* add `RESET` keycode to your keymap - this will also force it to enter the bootloader for 8 seconds
* hold down rotary encoder button while plugging in USB cable (or hit reset button once) to enter bootloader

Closed 2021-01-04.

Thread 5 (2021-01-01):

Rotary encoder: rotation not registered as input

breakawayt, 2021-01-01:
Hi,

Do you mind telling me the correct configuration for rotary encoder to work?
OS: Windows 10

**config.h file**
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

**Driver used**
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

**keymap.c**
*this is not working
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

breakawayt, 2021-01-01:
Found the solution.

**Hint**
https://github.com/imchipwood/dumbpad/issues/3#issuecomment-648270549

**Resolution**
Use configuration from: https://github.com/imchipwood/qmk_firmware/tree/dumbpad_refactor/keyboards/dumbpad/v1x

Closed 2021-01-01.

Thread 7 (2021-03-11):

Issue trying to print the gerbers at jlcpcb

zpeleg, 2021-03-11:
Hi, I tried producing the combo gerbers and got a response mail from jlcpcb and I'm not sure what they mean. They ask:

"As shown below, shall we make these indicated slots as plated slots, or the tin bath slots?"

What do they mean? What do I answer?

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

ephphatha, 2021-03-23:
It looks like they're indicating the ovalised slots used to anchor rotary encoders. The plating for those slots is for structural reasons (lets you solder some anchor tabs to hold the rotary encoders better). I'm not 100% sure what the different options they're talking about are but I suspect "tin bath slots" refers to making through hole plated slots and then treating them with a tinning solution to make them easier to solder, whereas "plated slots" would skip this tinning step. Since they're not electrical connections it doesn't really matter how they're plated so I'd go with whatever option is cheaper.

zpeleg, 2021-03-23:
Sorry for not updating! I thought that this is what they meant as well, but it's not. Apparently it's simply a bad translation and they meant either plated though holes or non plated through hole. I went with plated.

Just got the pcbs and waiting for the rest of the components. Will update with photos ;)

imchipwood, 2021-03-23:
Could've sworn I responded to this - but yes, these are plated slots for the ground/chassis pins of the encoder. You were correct to request they plate them!

Closed 2021-03-23.

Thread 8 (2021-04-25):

1.1 - QMK no device detected

Aldarith, 2021-04-25:
Hey Folks,

trying to flash some fresh firmware on my dumbpad.

No matter what I do, whenever I click 'Flash', QMK tells me no device is detected.

I have hit the reset ground pin, attempted to hold the ground pin while inserting cable, etc....

imchipwood, 2021-04-25:
Do any of the LEDs on the pro micro turn on? Can you program it using the Arduino IDE?

It sounds to me like your Pro Micro may be damaged, but it's hard to say without pictures of your solder job.

Aldarith, 2021-04-26:
Hey! Thanks for the quick response.

Yeah, it works fine! I flashed it once before but I forgot to add a '0' key so now I am attempting to correct that mistake.
All the buttons work as intended so far.

Aldarith, 2021-04-26:
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

I am sure I just have this set up wrong somehow...

imchipwood, 2021-04-26:
MCU seems correct, though last time I programmed any QMK boards from Windows I used dfu_util, not avrdude. That was almost a year ago now so maybe QMK changed which programmer QMK Toolbox uses.

My only guess is permissions WRT the com port - could try running QMK Toolbox as admin. If that doesn't work, you might want to take this to the QMK issue system or discord - it doesn't appear to specifically be a dumbpad problem.

imchipwood, 2021-12-08:
Closing this issue - please reopen if you're still experiencing this problem

Closed 2021-12-08.

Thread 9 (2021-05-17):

I'm a newbie

shaye1444, 2021-05-17:
I'm a newbie,

I was able to build my dumpad and everything then I tried to flash with QMK and now none of the keys work :( I'm really not sure what to do as I am not versed in programming. Any help for me?

Thanks!

imchipwood, 2021-05-17:
Hey - sorry to hear you're having issues, but I'm happy to help out!

Few questions for ya:
* What PCB version? 1.1 or something else?
* What layout? i.e. 1 encoder in the bottom left, dual encoder, etc.
* What operating system is your computer? Windows, macOS, etc.
* How did you build the firmware and flash it?
  * In case you built it yourself, you can now use [QMK Configurator](https://config.qmk.fm/#/dumbpad/v1x/LAYOUT) to build your firmware if you're not comfortable with programming.

imchipwood, 2021-12-08:
Closing issue due to lack of response. Please reopen if you still need assistance!

Closed 2021-12-08.

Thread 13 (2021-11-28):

Dumbpad issue

tarnis, 2021-11-28:
probably is a better way to test the pcb before I started but I'm not 100% sure what to touch to what on the voltmeter :)

my buttons seem to be working testing ok for continuity touching the probes where I soldered, but the circled ones aren't functioning still.  Wasn't sure if there was a common point maybe on the pro micro I might need to resolder?

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

imchipwood, 2021-11-28:
Rows each have their own pin, and columns each have their own pin. The row you've circled is ROW2 which is connected to A1.

The other switch you've circled (row 3, column 3), since the problem is isolated to a single switch, it's probably the diode. Check its polarity.

tarnis, 2021-11-30:
Thanks, a little more solder on both fixxed it...good thing as I can't remove that plastic mount really without removing all of the switches.

If you don't mind my asking, where would I look to see how things are assigned to each pin?  Eventually I think I'm looking to make a controller for a car I built with something like this and making my own pcb.

Thanks,
Matt

imchipwood, 2021-11-30:
Woo! Glad you got it working!

Look at the .brd (board) and .sch (schematic) files using Eagle. Columns are ordered 0-4 from left to right, where column 0 is just the single encoder under the pro micro. Rows are ordered 0-3 from top to bottom.

If you click a wire in the board file and then click the 'i' information button it'll give you the name of the wire (ROW0, COL3, etc.). Switch over to the schematic and you can see which pin on the pro micro that connects to.

imchipwood, 2021-11-30:
Woo! Glad you got it working!

Look at the .brd (board) and .sch (schematic) files using Eagle. Columns are ordered 0-4 from left to right, where column 0 is just the single encoder under the pro micro. Rows are ordered 0-3 from top to bottom.

If you click a wire in the board file and then click the 'i' information button it'll give you the name of the wire (ROW0, COL3, etc.). Switch over to the schematic and you can see which pin on the pro micro that connects to.

Closed 2021-12-08.

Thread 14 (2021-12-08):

Is this compatible with Choc switches?

Hate9, 2021-12-08:

imchipwood, 2021-12-08:
No - CHOC and Cherry MX sockets are not compatible. The pins are laid out a little differently on the bottom.

Closed 2021-12-08.

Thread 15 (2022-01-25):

Change VENDOR_ID in QMK firmware for proper VIA compatibility

mpfl, 2022-01-25:
Theoretically this is an issue to raise in the QMK repo, but I wanted to get your attention.

It looks like the VENDOR_ID for the Dumbpad is still the default of 0xFEED.

Would you be able to change the VENDOR_ID so that I can submit my VIA config to VIA? Alternatively, I would be happy to change the VENDOR_ID and submit a PR. Figure it would be polite to ask you first since you're the Dumbpad's creator!

imchipwood, 2022-01-25:
Huh, thought I'd changed it to DEAF or something else silly.. Anyway thanks
for contacting me first - I don't really care what the vendor ID is so long
as the device ID still shows up as 'dumbpad' when plugged in!

Feel free to change it!

On Mon, Jan 24, 2022, 11:29 PM Matthias Liffers ***@***.***>
wrote:

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

medoix, 2022-08-05:
Just noting that my PR to merge in the OLED firmware also makes the ```VENDOR_ID``` change here https://github.com/qmk/qmk_firmware/pull/17058/files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

This will then unblock the one current reason for no VIA support in this PR https://github.com/the-via/keyboards/pull/1255

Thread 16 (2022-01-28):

Mill Max compatible?

deveth0, 2022-01-28:
Hey, thank you so much for the board layouts!
I plan to build a "hotswap" able version, do you know by any chance, if the board i compatible to Mill Max sockets?

Cheers

imchipwood, 2022-01-28:
Never heard of them - unless they have the same pin locations as a cherry
MX switch, they won't be compatible.

On Fri, Jan 28, 2022, 6:40 AM Alex Muthmann ***@***.***>
wrote:

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

deveth0, 2022-01-28:
oh wow, that's fast, thanks!
Mill max are just soldered into the wholes and provide some kind of hotswap for all kind of switches:
https://keygem.store/products/mill-max-hot-swap-sockets?_pos=1&_sid=fd8fb5200&_ss=r

imchipwood, 2022-01-28:
Hmm, looks like it should work. I can't remember exactly but the holes should be the standard 0.060" (1.524mm). [This page](https://www.mill-max.com/search/tags/hot--swap-socket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) shows the sleeve outer diameter at just under that (0.058" (1.47mm)), so they should squeeze in there.

Let me know if you try it out - I'm not much of a hot swapper but I've never seen these before and am curious how well they hold onto a switch!

deveth0, 2022-02-08:
Sorry, can't provide feedback here as I did not order your PCB  :(

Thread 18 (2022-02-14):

VIA Issue, no device detected.

Pushingboii, 2022-02-14:
i'm a newb, got my dumbpad flashed by my friend. It works, but i cant change the layout from via configurator. I'm using v1.1 pcb.
Thanks, and sorry for my broken english.

imchipwood, 2022-02-14:
dumbpad is not currently supported in VIA.

@jfescobar18 [completed a PR in qmk_firmware](https://github.com/qmk/qmk_firmware/pull/13512) to add VIA support but it was reverted due to issues. I haven't looked into this since I don't use VIA...

Sorry :/

Pushingboii, 2022-02-16:
Okay then, thanks for your information, my friend said i have to use Vial app to change the layout.
Support from Indonesia....
And again, sorry for my broken english.

Closed 2022-02-16.

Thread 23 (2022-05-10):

hot swap, rgb and oled

ykz89, 2022-05-10:
Hi,

Now that there is a hotswap/rgb version and an oled version, is there any chance you could create a version with all of those features?

imchipwood, 2022-05-11:
[That idea has actually already been floated](https://github.com/imchipwood/dumbpad/pull/20#issuecomment-1109500930) :)

But, at the moment, neither the OLED or RGB versions are supported by the QMK master branch - therefore do not work with VIA or the QMK configurator out-of-the-box... [There is a PR](https://github.com/qmk/qmk_firmware/pull/16285) to get the RGB version supported, I'll apply some pressure to get that in...

@medoix what changes were made to QMK support the OLED version? Could they be merged into QMK's master branch?

ykz89, 2022-05-11:
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

Is it perhaps an idea to include the changes needed, in this repository until it is merged into QMK?

medoix, 2022-05-11:
@imchipwood i have created a [PR for VIA](https://github.com/the-via/keyboards/pull/1255) support of the dumbpad in general, the OLED version has the same switch/encoder layout so would be configurable by VIA the same.

I have just raised a [QMK PR](https://github.com/qmk/qmk_firmware/pull/17058) for the OLED version.

imchipwood, 2022-05-11:
@ykz89 I don't really want to keep any code in this repo, and it looks like all of the QMK changes needed for OLED + RGB are in PR so I don't have to! If we get a PCB design finished before the QMK PRs go thru we will certainly add a link to the appropriate branches in the README.

I'll look into making an rgb+hotswap+oled version this weekend - I need to learn KiCad anyway and this is a small enough change to the RGB version it should be a good learning experience.

bagges, 2022-06-09:
@imchipwood How's your KiCad learning going? :-)

imchipwood, 2022-06-09:
> @imchipwood How's your KiCad learning going? :-)

Well, I installed KiCad on my desktop... :P

TimoWielink, 2022-08-21:
Happy to Contribute to creating this version, But I am struggling with the use of Both KiCad and Eagle. Happy to collaborate to come up with a better system for the different boards (And also work on the naming?).

@imchipwood Did you manage to work on an Oled + RGB + Hotswap version, seems like this has been open for a while. Very happy to pick up any work and support the project.

imchipwood, 2022-08-21:
Unfortunately, no work has been done on this... Too busy with summer stuff!

In all reality I likely won't work on any personal projects until the
middle of next year due an 8 month class/training that starts soon..

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

TimoWielink, 2022-08-22:
No worries, I will see what I can do! I just ordered a batch of PCBs and will see how they turn out.

p.s. Not related to this issue, but is there a space where roadmap, features etc are being discussed for the dumbpad?

imchipwood, 2022-08-22:
Nope, no plans or place to discuss them... Open to suggestions, though!

TimoWielink, 2022-08-24:
@imchipwood Could be interested to spin up a Discord or Slack. I can give it some thought over the weekend and share my progress on my build and plans for it.

Thnx

dickofn, 2022-10-11:
I'm bumping the old PR for this and following up with the reviewers

all credit goes to @imchipwood and @deveth0 , if you don't like my action, please let me know, and I'll take down the PR
this PR is essentially your PR with modifications as requested by the reviewer before the PR is closed

dickofn, 2022-10-11:
**New Update for V3X**

I've just submitted a PR to Vial https://github.com/vial-kb/vial-qmk/pull/261
it includes rotary encoder support and RGB matrix with VIAL software

It's been hard having no official support, but now it'll be over soon cheers 🥂

Credit goes to:
Board @imchipwood
QMK for v3x @deveth0

imchipwood, 2022-10-11:
Thanks for getting via/vial working! Hopefully the PR goes through soon and we can link users to the various GUIs they can build firmware with.

dickofn, 2022-10-11:
you're welcome sir, I need this device to be more user-friendly because I want to gift my other dumbpad to less techy guys

dickofn, 2022-10-12:
It's finally merged to vial master https://github.com/vial-kb/vial-qmk

dickofn, 2022-10-13:
And also in qmk master, cheers 🥂
https://github.com/qmk/qmk_firmware

nuddler, 2025-02-04:
Is it possible to get combo_oled with hot_swap ?

imchipwood, 2025-02-05:
> Is it possible to get combo_oled with hot_swap ?

I have no plans to work on dumbpad anymore - any updates will have to come from the community. Feel free to design it yourself :)

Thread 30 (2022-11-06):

KiCad files for "combo" broken?

spi5498, 2022-11-06:
Hello!

Tried to open up the combo kicad project, however, it seem broken.

Opening up the .sch file gives me dumbpad.sch is not a eeschema file.

Attempted the rgb and that one works fine. Any ideas?

imchipwood, 2022-11-06:
Not near a computer but pretty certain the combo files are Eagle files, not
KiCad!

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

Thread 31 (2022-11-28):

Dumbpad trouble

Hintaa, 2022-11-28:
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
I just finished flashing my dumbpad but the two circled columns wont work

imchipwood, 2022-11-28:
Check your soldering on all the pins for those switches, the diodes next to them, and the pins on the arduino for those columns. Double check diodes are the correct direction.

If you have a multimeter, you can check the voltage on the column pins while pressing buttons. It should change, not 100% sure what values you should see and not currently at home to double check.

Hintaa, 2022-11-28:
Which pins on the arduino should they be?
should it be the 8 &9 on the left side pf the arduino

imchipwood, 2023-02-02:
Sorry for the long silence - are you still having issues? Would need to sit down and look things over to verify pin connections.

Hintaa, 2023-02-03:
Yes I am still having trouble

Hintaa, 2023-02-03:
oop sorry accident

imchipwood, 2025-02-05:
@Hintaa are you still having issues? I would like to close this if you resolved the issue.

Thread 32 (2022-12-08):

Rotary encoder

Hintaa, 2022-12-08:
I'm confused on how to program my rotary encoder to be vol up and down and when pressed media stop I was wondering if you could send me a .json file with the said features so i can use it

TimoWielink, 2023-01-02:
What setup are you using (placement of the encoder) and what Arduino? I can send you a Binary file or help you setup QMK config.

imchipwood, 2023-02-02:
Closing due to lack of response. Please open new issue if you still have troubles with the encorder.

Hintaa, 2023-02-03:
The rotary encoder is on the bottom left and the rest is all switches
sorry for the late reply

On Tue, Jan 3, 2023 at 1:24 AM Timo Wielink ***@***.***>
wrote:

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

Closed 2023-02-02.

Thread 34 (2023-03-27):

Dumbpad not working with any firmware I got from QMK configurator

TylerWang2, 2023-03-27:
My dumbpad PCB version is 1.1, 17 keys, encoder on the bottom left, with an OLED display

The keys itself is working as I found some random firmware to flash it and it is working. As soon as i use one of my own configuration from QMK configurator non of the keys work

imchipwood, 2023-03-27:
17 keys with encoder on the bottom left? Do you mean 16 keys?

Export your QMK configurator config as JSON and paste it into here - I'll try to look at it today or tomorrow to see if I can reproduce the problem.

TylerWang2, 2023-03-28:
sorry, yes.
Here is the JSON:
{
    "name": "DUMBPAD V1.1",
    "vendorId": "0xA153",
    "productId": "0xF3BE",
    "lighting": "none",
    "matrix": { "rows": 4, "cols": 5 },
    "layouts": {
      "keymap": [
        [{"x": 1.25}, "0,1", "0,2", "0,3", "0,4"],
        [{"x": 1.25}, "1,1", "1,2", "1,3", "1,4"],
        [{"x": 1.25}, "2,1", "2,2", "2,3", "2,4"],
        ["3,0", {"x": 0.25}, "3,1", "3,2", "3,3", "3,4"]
      ]
    }
  }

imchipwood, 2023-04-16:
Sorry I took so long to get back.

I didn't notice you mentioned the OLED version in your original issue - I actually cannot help you much with that one as I do not have an OLED version (I did not design that one). You'll want to talk to the guy behind keebd: https://github.com/keebd/dumbpad

Closed 2023-04-16.

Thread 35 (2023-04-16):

Troubleshooting help

afishydeath, 2023-04-16:
Hi there, I recently purchased the oled version from keebd, and after soldering it all together today, only the reset button and the knob are recognized. I have tried continuity tests from the pins of the pro micro through the switches, and using diode mode on my multimeter everything looks like expected, however after multiple attempts with different versions of firmware (starting with the ones on keebd's website, I still get 0 output from the switches in tests. Any advice on how to troubleshoot would be appreciated.

Slightly more info on continuity testing. I specifically checked the top left key, the row pin is f4 and the column pin is e6, i get continuity when pressed, but still nothing in a keyboard test, using suggested firmware

imchipwood, 2023-04-16:
So, keyboards measure keypresses in a row/column matrix. A single key press causes a voltage drop across a diode on two pins - a row pin, and a column pin. Multiple keypresses compound this - by measuring the voltage on each pin of the matrix, you can determine which

Therefore, measuring the continuity from _one_ pin doesn't really tell you much of anything. In order for a single key to work, continuity must be good between each key, diode, _and_ microcontroller pin for the entire row and column.

I would open the schematic for the combo_oled board (download KiCAD), and check continuity between every single connection.

Or just resolder every single diode/switch/microcontroller pin..

afishydeath, 2023-04-16:
Okay, I'll give that a try.

imchipwood, 2023-07-27:
Closing issue due to no updates in a few months. Please reopen if you're still having issues.

Closed 2023-07-27.

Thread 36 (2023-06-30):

Dumbpad issue...switches not working

tarnis, 2023-06-30:
Hi, building a second dumbpad tonight, the column next to the rotory encoder slot and led's isn't working.  What is that linked to?

Great job on this board design btw!

imchipwood, 2023-06-30:
Which version did you build?
-Chip

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

tarnis, 2023-06-30:
Promicro

imchipwood, 2023-06-30:
They all use a pro micro... Rgb? Oled? No LEDs?

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

tarnis, 2023-07-01:
Lol...just the 3 LEDs above the rotary encoder.  Not a fancy one.  Combo I guess.  😁. Made these a long time ago.

imchipwood, 2023-07-01:
Column 1 is pin D6 on the Pro Micro

Columns are numbered 0-4 from left to right, rows are 0-3 from top to bottom
[image: image.png]
-Chip

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

imchipwood, 2023-07-01:
Image failed to send via email...
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

tarnis, 2023-07-01:
That did the trick, appreciate your help!  Wish these worked with the hot swap sockets I bought....case looks like a trainwreck now 😞

Closed 2023-07-01.

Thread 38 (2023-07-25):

Led 16 not working on dumbpad v3 hotswap

danlniel, 2023-07-25:
So i just built my first dumbpad, but the last LED (LED 16) didn't work. I have already checked with a multimeter and changed the LED, any idea why?

imchipwood, 2023-07-25:
What did you check with a multimeter? You can really only check that the signals are _connected_ properly, but a DMM isn't very useful to see what signals the LED is receiving.

I didn't design that board so I don't have a whole lot of advice regarding it - the LEDs are all wired in sequence so if you have 15 working LEDs and one broken one, it's likely the LED is actually dead, or the pads that it attaches to are damaged.

danlniel, 2023-07-26:
> You can really only check that the signals are connected properly

Yes i only check to make sure the signals are sent and received well

> but a DMM isn't very useful to see what signals the LED

I see

So far i dont think the LED is broken, i have a lot spare of LED and all are not working, most likely then the pads were damaged when I soldered. Thanks for help me investigate this problem, i will recheck again the board sooner and in the meantime i think i will order a new board.

Closed 2023-07-26.

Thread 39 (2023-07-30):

it simply doesn't work

csmayen, 2023-07-30:
Hello, when I connect the Pro micro to QMK Toolbox recognizes it perfectly as a dumbpad but when I place it on the keyboard it simply doesn't work, not even the reset button. All the soldering seems correct.

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

imchipwood, 2023-07-30:
Sounds like something is shorted, probably reset to ground or vcc or some
other nearby pin.

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

imchipwood, 2025-02-05:
Closing issue - no responses in over a year.

Closed 2025-02-05.

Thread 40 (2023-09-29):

Led question from a newbie

cgdsyldrm, 2023-09-29:
Hello, first and foremost thank you for sharing this beautiful macropad. I tried to find my answer another other issues but I couldn't.

So I am a new to this, both building a custom macropads and soldering but I'm getting there. Is it possible to add those circular led as in the photos? If so, do I need to solder them with a resistor or something? Also do I need to do something with the code?

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

imchipwood, 2023-09-29:
I can't tell which board you're using but none of the boards are set up to use thru-hole LEDs in that way - the routing is very difficult on 2-layer PCBs, and since there's an RGB LED version available, I've never bothered to attempt the routing.

cgdsyldrm, 2023-09-30:
Hello @imchipwood, the board is oled version, I see and thank you for the clarification.

Closed 2023-09-30.

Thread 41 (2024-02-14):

How to disable running numpad on first/base layer

adrase, 2024-02-14:
Ok, this drive me crazy. What should be done to not have enabled numpad?
I've got two layers and first one is always replaced with numpad. After I plug keyboard I have arrows, pgup, pgdn, ins etc on first layer but not digits and not what I specified in keymap. Also first led is on.

Second layer works ok. I work on Ubuntu 22.04
What and where should I change in order to have base layer specified by me and not numpad? Thanks.

Here is my keymap:

```
#include QMK_KEYBOARD_H

// Tap Dance declarations
//enum {
//    TD_TG_NUM,
//};

// Tap Dance definitions
//tap_dance_action_t tap_dance_actions[] = {
    // Tap once for Escape, twice for Caps Lock
//    [TD_TG_NUM] = ACTION_TAP_DANCE_DOUBLE(TG(1), KC_NUM),
//};

enum custom_layers {
    _BASE,
    _SUB,
};

const uint16_t PROGMEM keymaps[][MATRIX_ROWS][MATRIX_COLS] = {
    /*
            BASE LAYER
    /-----------------------------------------------------`
    |             |    7    |    8    |    9    |  /  |
    |             |---------|---------|---------|---------|
    |             |    4    |    5    |    6    |   *  |
    |             |---------|---------|---------|---------|
    |             |    1    |    2    |    3    |   +   |
    |-------------|---------|---------|---------|---------|
    |       mute  |    0    |    .    |    -    |  switch  |
    \-----------------------------------------------------'
    */
    [_BASE] = LAYOUT(KC_P7, KC_P8, KC_P9, KC_PSLS,
                 KC_P4, KC_P5, KC_P6, KC_PAST,
                 KC_P1, KC_P2, KC_P3, KC_PPLS,
        KC_MUTE, KC_P0, KC_PDOT, KC_PMNS, TG(_SUB)
    ),
    /*

    /------------------------------------------------------------------`
    |             |  ctrl s  |   pg up   |   ]          |  wheel up   |
    |             |----------|-----------|--------------|-------------|
    |             |  B       |   pg down |   [          |  wheel down |
    |             |----------|-----------|--------------|-------------|
    |             |   shft i |   H       | shft ctrl a  |  Ins        |
    |-------------|----------|-----------|--------------|-------------|
    |    mute     |   E      |  space    |  ctrl z      |  switch     |
    \-----------------------------------------------------------------'
    */
    [_SUB] = LAYOUT(LCTL(KC_S), KC_PGUP, KC_RBRC, KC_WH_U,
                 KC_B, KC_PGDN, KC_LBRC, KC_WH_D,
                 LSFT(KC_I), KC_H, LCTL(LSFT(KC_A)), KC_INS,
        KC_MUTE, KC_E, KC_SPC, LCTL(KC_Z), TG(_SUB)
    )

};

const uint16_t PROGMEM combo1[] = {KC_P0, KC_PDOT, COMBO_END};
const uint16_t PROGMEM combo2[] = {KC_PDOT, KC_PMNS, COMBO_END};

combo_t key_combos[] = {
    COMBO(combo1, KC_BSPC),
    COMBO(combo2, KC_ENT),
};
```

imchipwood, 2024-02-14:
This is more of a question for the QMK community than me... but anyway. What happens when you only define one layer?

Basically, simplify your keymap until you no longer find the issue, then start adding features back in one by one.

I've never run into an issue like this on a healthy dumbpad.

adrase, 2024-02-15:
Probably you are right I must have messed something. Anyway, I found solution. Maybe not pretty but it works:

`layer_state_t layer_state_set_user(layer_state_t state) {
    switch (get_highest_layer(state)) {
    case _BASE:
        if (!host_keyboard_led_state().num_lock) {
             tap_code16(KC_NUM);
        }
        break;
    default: //  for any other layers, or the default layer
        if (!host_keyboard_led_state().num_lock) {
             tap_code16(KC_NUM);
        }
        break;
    }
  return state;
}`

imchipwood, 2025-02-05:
Closing this since there is a workaround and it's not a dumbpad-specific issue.

Closed 2025-02-05.

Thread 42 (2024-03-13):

3mm led orientation.

Sagzster, 2024-03-13:
I was wondering what the orientation of the 3 possible 3mm led's are? anode towards rotary encoder or the Arduino?  Its not indicated on the PCB.

Thanks!
Brad

imchipwood, 2024-03-13:
The cathode is towards the encoder - you can see tiny tabs from the solder
pad connecting it to the ground plane.

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

Sagzster, 2024-03-15:
Thank You!

Closed 2024-03-15.

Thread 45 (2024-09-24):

Footprint for SK6812MINI

TimoWielink, 2024-09-24:
@deveth0

Hi There,

I have a question, I am working on a Redesign of your HotSwap LED version, I have been working with your KiCad files but then I noticed my footprint doesn't have the Edge Cuts for the LED lights, did you create those manually or are those part of an updates footprint you created?

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

TimoWielink, 2024-09-24:
Found it!

Closed 2024-09-24.

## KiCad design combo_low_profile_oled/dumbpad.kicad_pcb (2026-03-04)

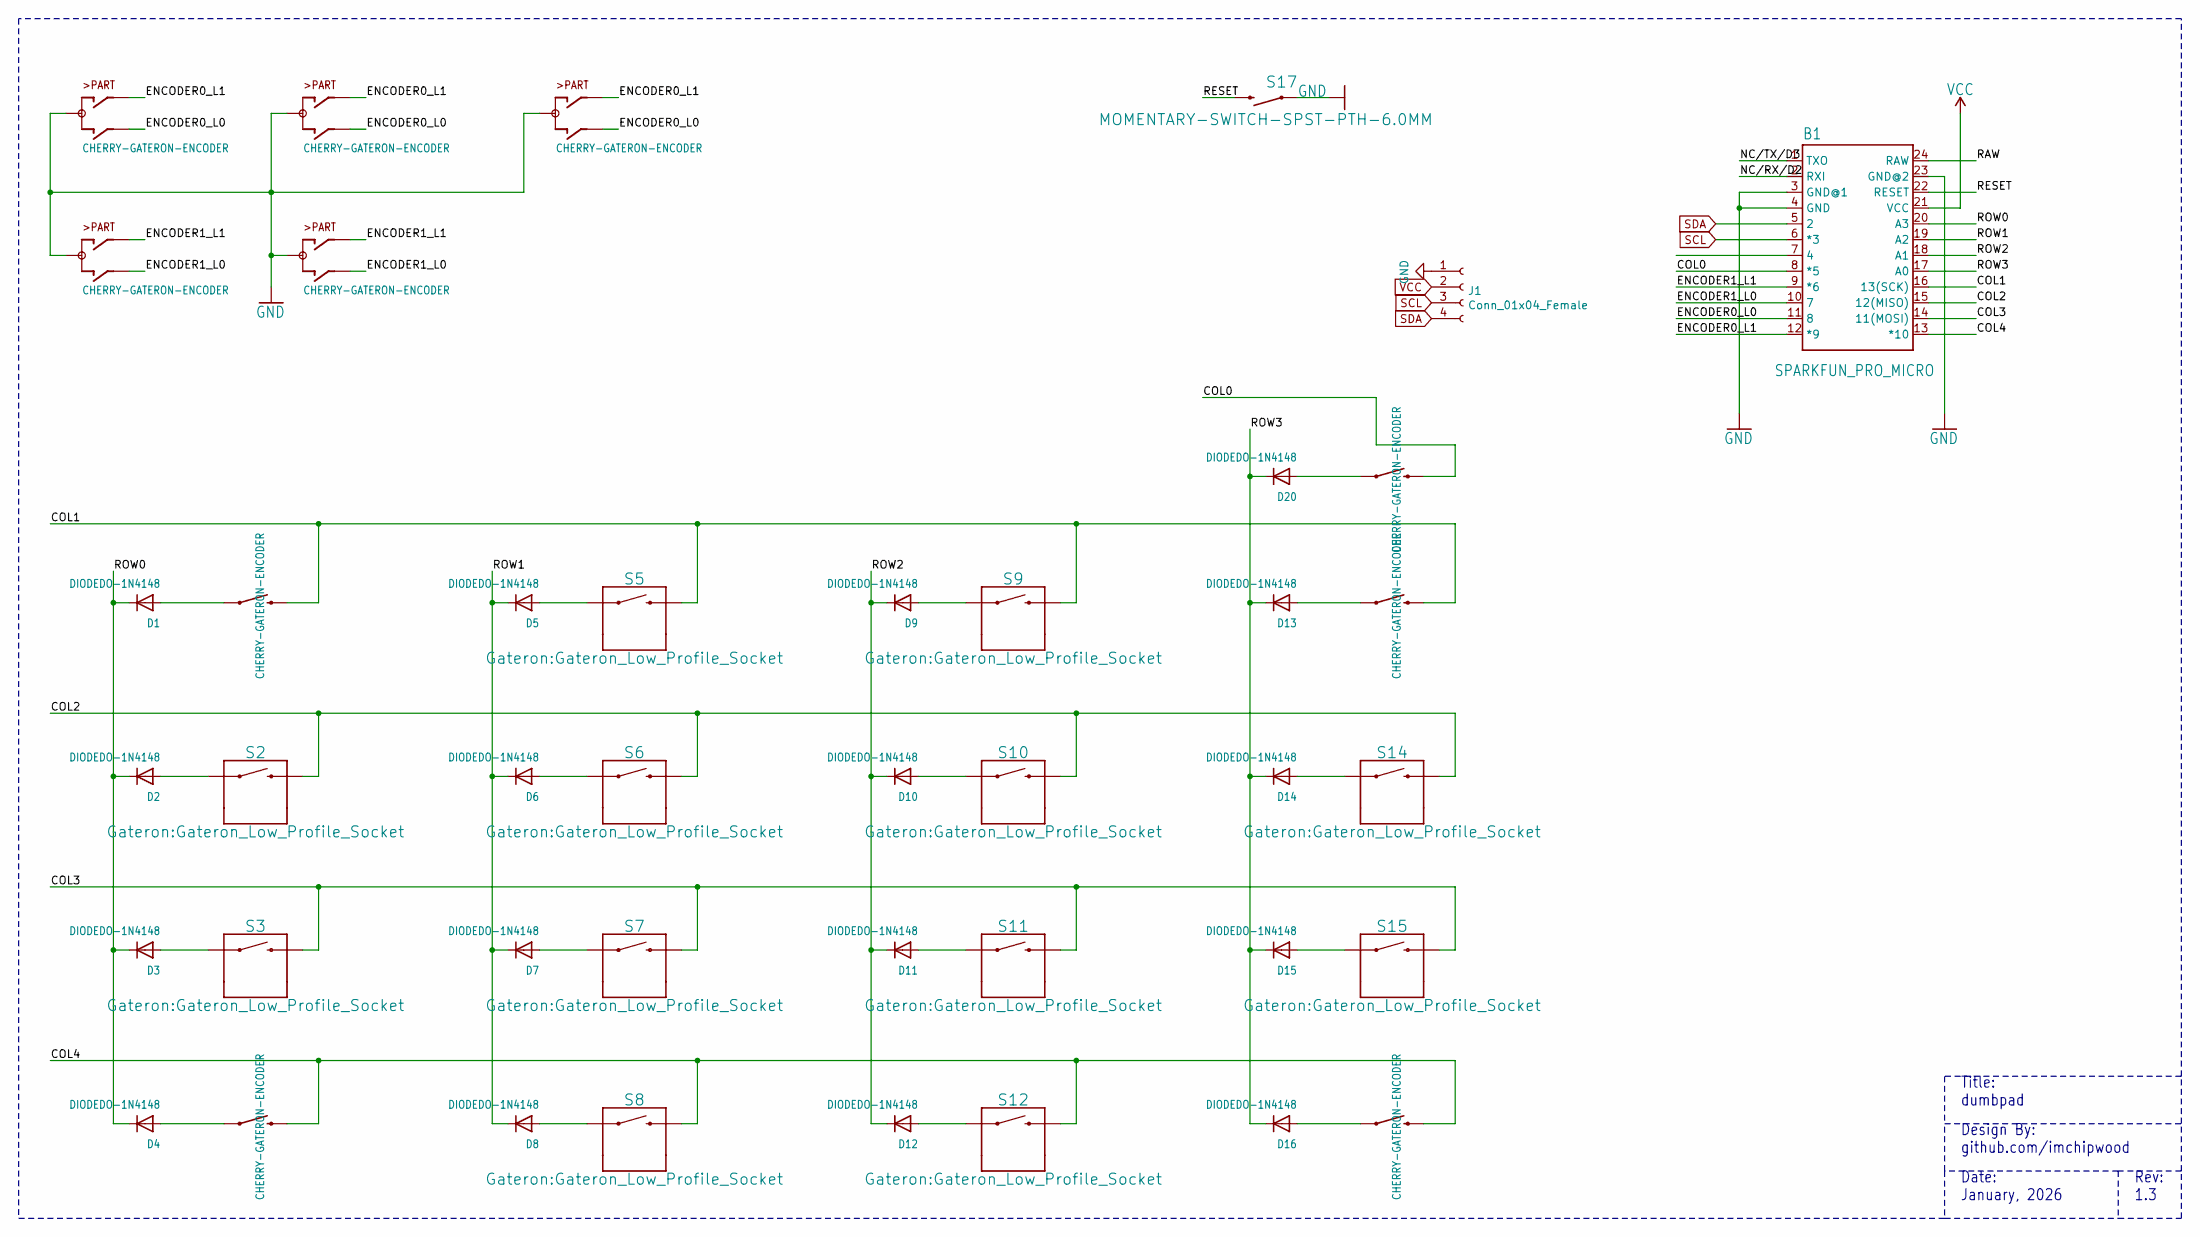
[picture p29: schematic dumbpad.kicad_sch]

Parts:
B1: SPARKFUN_PRO_MICRO
D1, D2, D3, D4, D5, D6, D7, D8, D9, D10, D11, D12, D13, D14, D15, D16, D20: DIODEDO-1N4148; DO-1N4148
J1: Conn_01x04_Female; OLED
RE_0_1, RE_0_4, RE_3_0, RE_3_1, RE_3_4: CHERRY-GATERON-ENCODER
S2, S3, S5, S6, S7, S8, S9, S10, S11, S12, S14, S15: Gateron:Gateron_Low_Profile_Socket; Gateron_Low_Profile_Socket
S17: MOMENTARY-SWITCH-SPST-PTH-6.0MM; TACTILE_SWITCH_PTH_6.0MM

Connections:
/COL0: B1.8 (*5), RE_3_0.E (2), RE_3_0.S2 (2)
/COL1: B1.16 (13(SCK)), RE_0_1.E (2), RE_0_1.S2 (2), RE_3_1.E (2), RE_3_1.S2 (2), S5.S2 (2), S9.S2 (2)
/COL2: B1.15 (12(MISO)), S2.S2 (2), S6.S2 (2), S10.S2 (2), S14.S2 (2)
/COL3: B1.14 (11(MOSI)), S3.S2 (2), S7.S2 (2), S11.S2 (2), S15.S2 (2)
/COL4: B1.13 (*10), RE_0_4.E (2), RE_0_4.S2 (2), RE_3_4.E (2), RE_3_4.S2 (2), S8.S2 (2), S12.S2 (2)
/ENCODER0_L0: B1.11 (8), RE_0_1.B, RE_3_0.B, RE_3_1.B
/ENCODER0_L1: B1.12 (*9), RE_0_1.A, RE_3_0.A, RE_3_1.A
/ENCODER1_L0: B1.10 (7), RE_0_4.B, RE_3_4.B
/ENCODER1_L1: B1.9 (*6), RE_0_4.A, RE_3_4.A
/NC/RX/D2: B1.2 (RXI)
/NC/TX/D3: B1.1 (TXO)
/RAW: B1.24 (RAW)
/RESET: B1.22 (RESET), S17.3 (2)
/ROW0: B1.20 (A3), D1.C, D2.C, D3.C, D4.C
/ROW1: B1.19 (A2), D5.C, D6.C, D7.C, D8.C
/ROW2: B1.18 (A1), D9.C, D10.C, D11.C, D12.C
/ROW3: B1.17 (A0), D13.C, D14.C, D15.C, D16.C, D20.C
GND: B1.3 (GND@1), B1.4 (GND), B1.23 (GND@2), J1.1, RE_0_1.C, RE_0_4.C, RE_3_0.C, RE_3_1.C, RE_3_4.C, S17.1
unnamed: D1.A, RE_0_1.D (1), RE_0_1.S1 (1)
unnamed: D4.A, RE_0_4.D (1), RE_0_4.S1 (1)
unnamed: D13.A, RE_3_1.D (1), RE_3_1.S1 (1)
unnamed: D16.A, RE_3_4.D (1), RE_3_4.S1 (1)
unnamed: D20.A, RE_3_0.D (1), RE_3_0.S1 (1)
unnamed: D2.A, S2.S1 (1)
unnamed: D3.A, S3.S1 (1)
unnamed: D5.A, S5.S1 (1)
unnamed: D6.A, S6.S1 (1)
unnamed: D7.A, S7.S1 (1)
unnamed: D8.A, S8.S1 (1)
unnamed: D9.A, S9.S1 (1)
unnamed: D10.A, S10.S1 (1)
unnamed: D11.A, S11.S1 (1)
unnamed: D12.A, S12.S1 (1)
unnamed: D14.A, S14.S1 (1)
unnamed: D15.A, S15.S1 (1)
SCL: B1.6 (*3), J1.3
SDA: B1.5 (2), J1.4
VCC: B1.21 (VCC), J1.2

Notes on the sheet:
Title: dumbpad
Design By: github.com/imchipwood
Rev: 1.3
Date: January, 2026

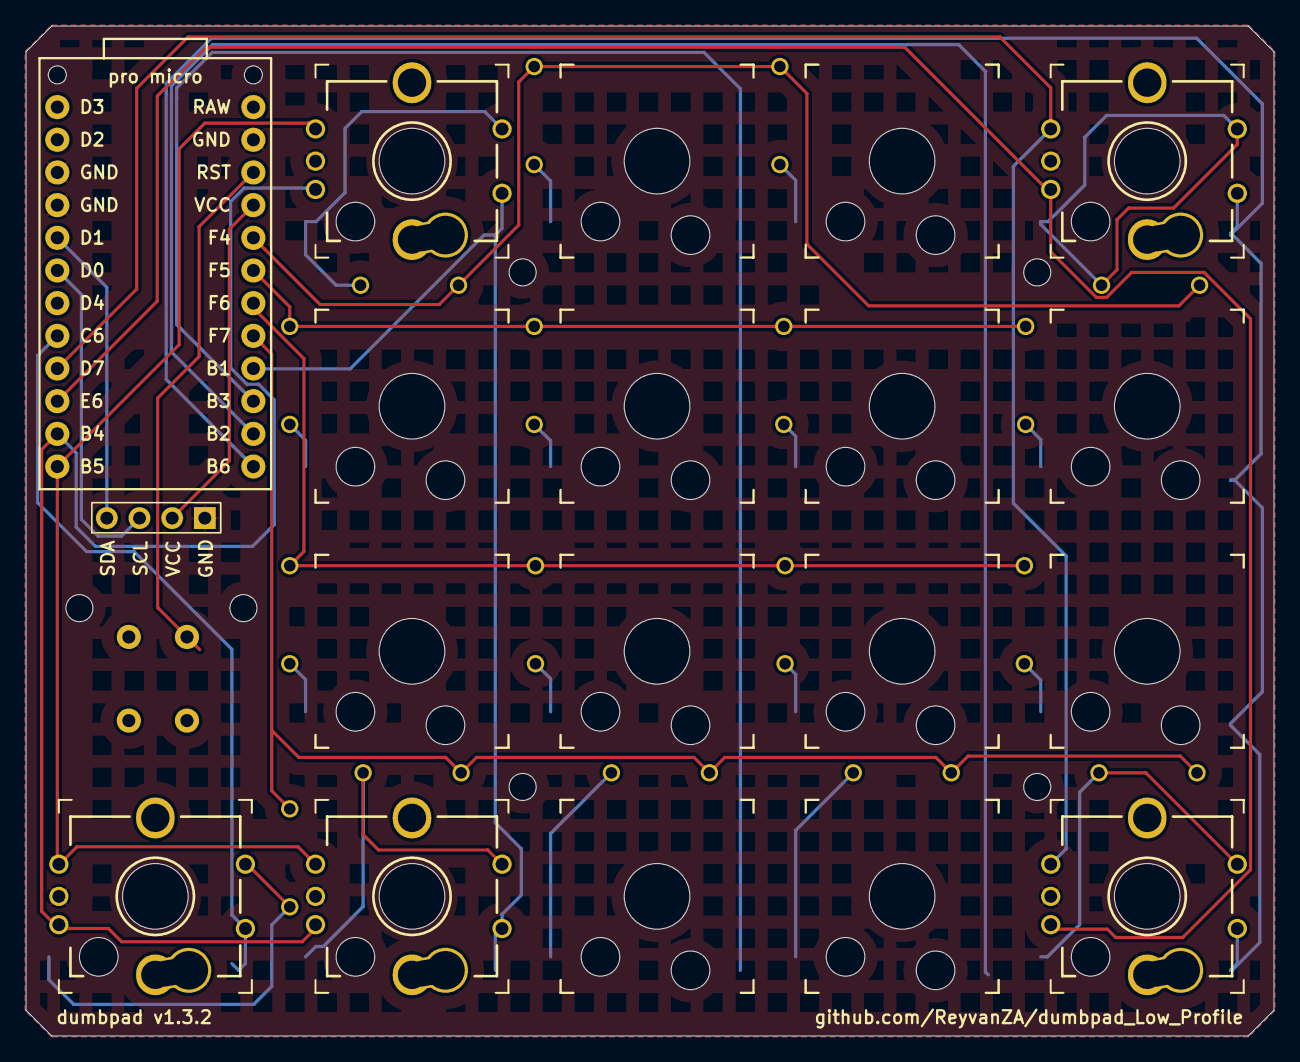
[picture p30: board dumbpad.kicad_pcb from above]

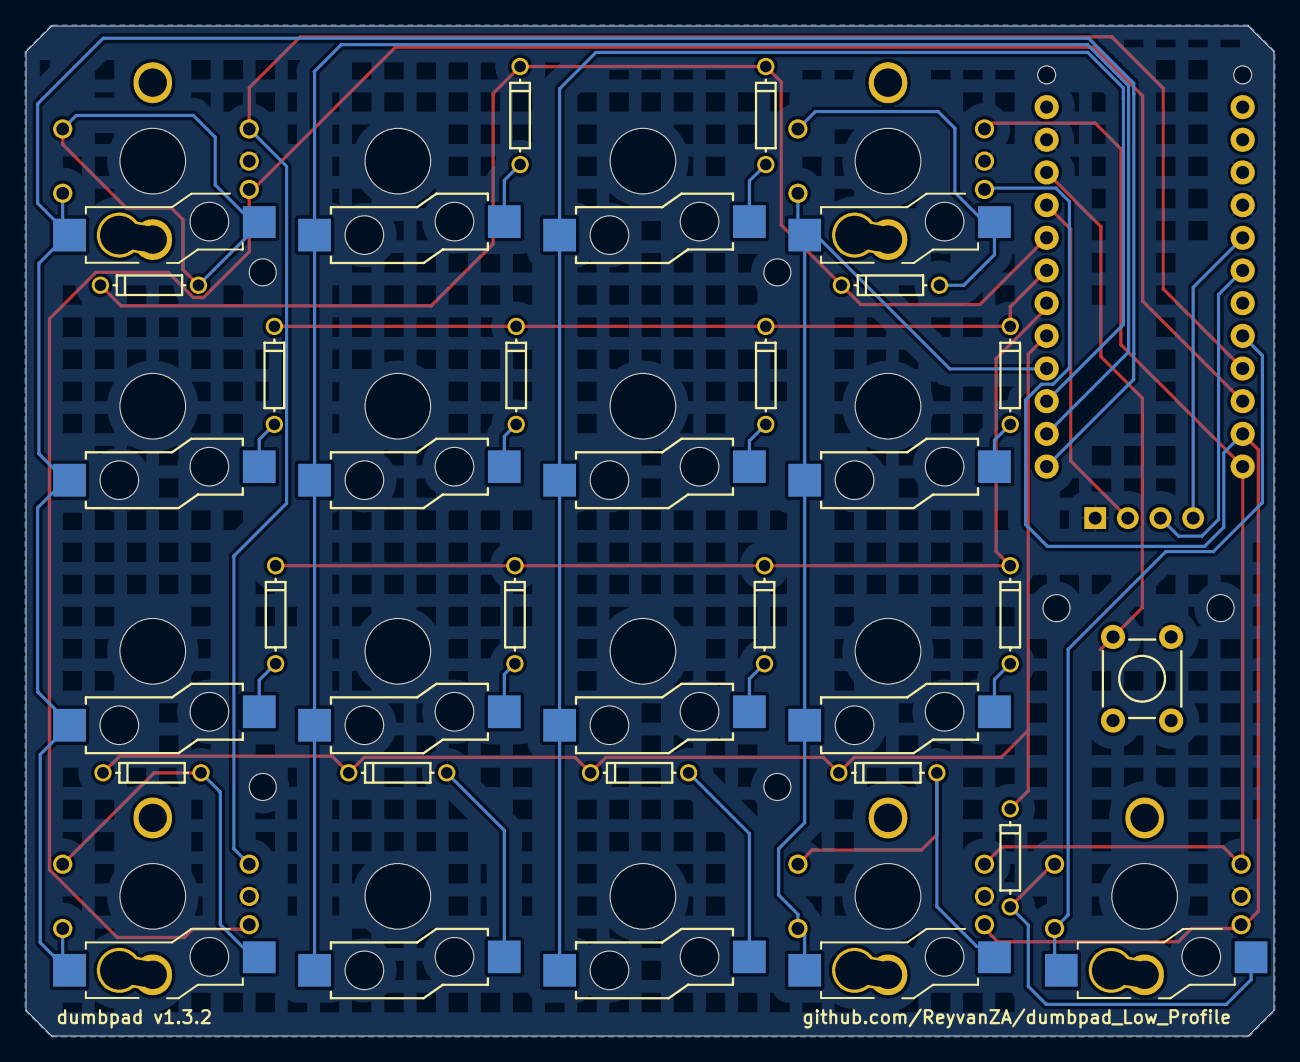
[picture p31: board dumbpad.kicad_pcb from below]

Board: 2 copper layers, 97.0 x 78.5 mm, 43 parts (18 on the bottom side), 35 nets.

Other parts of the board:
MH1, MH1#2, MH1#3, MH2, MH3, MH4: MountingHole_2.1mm

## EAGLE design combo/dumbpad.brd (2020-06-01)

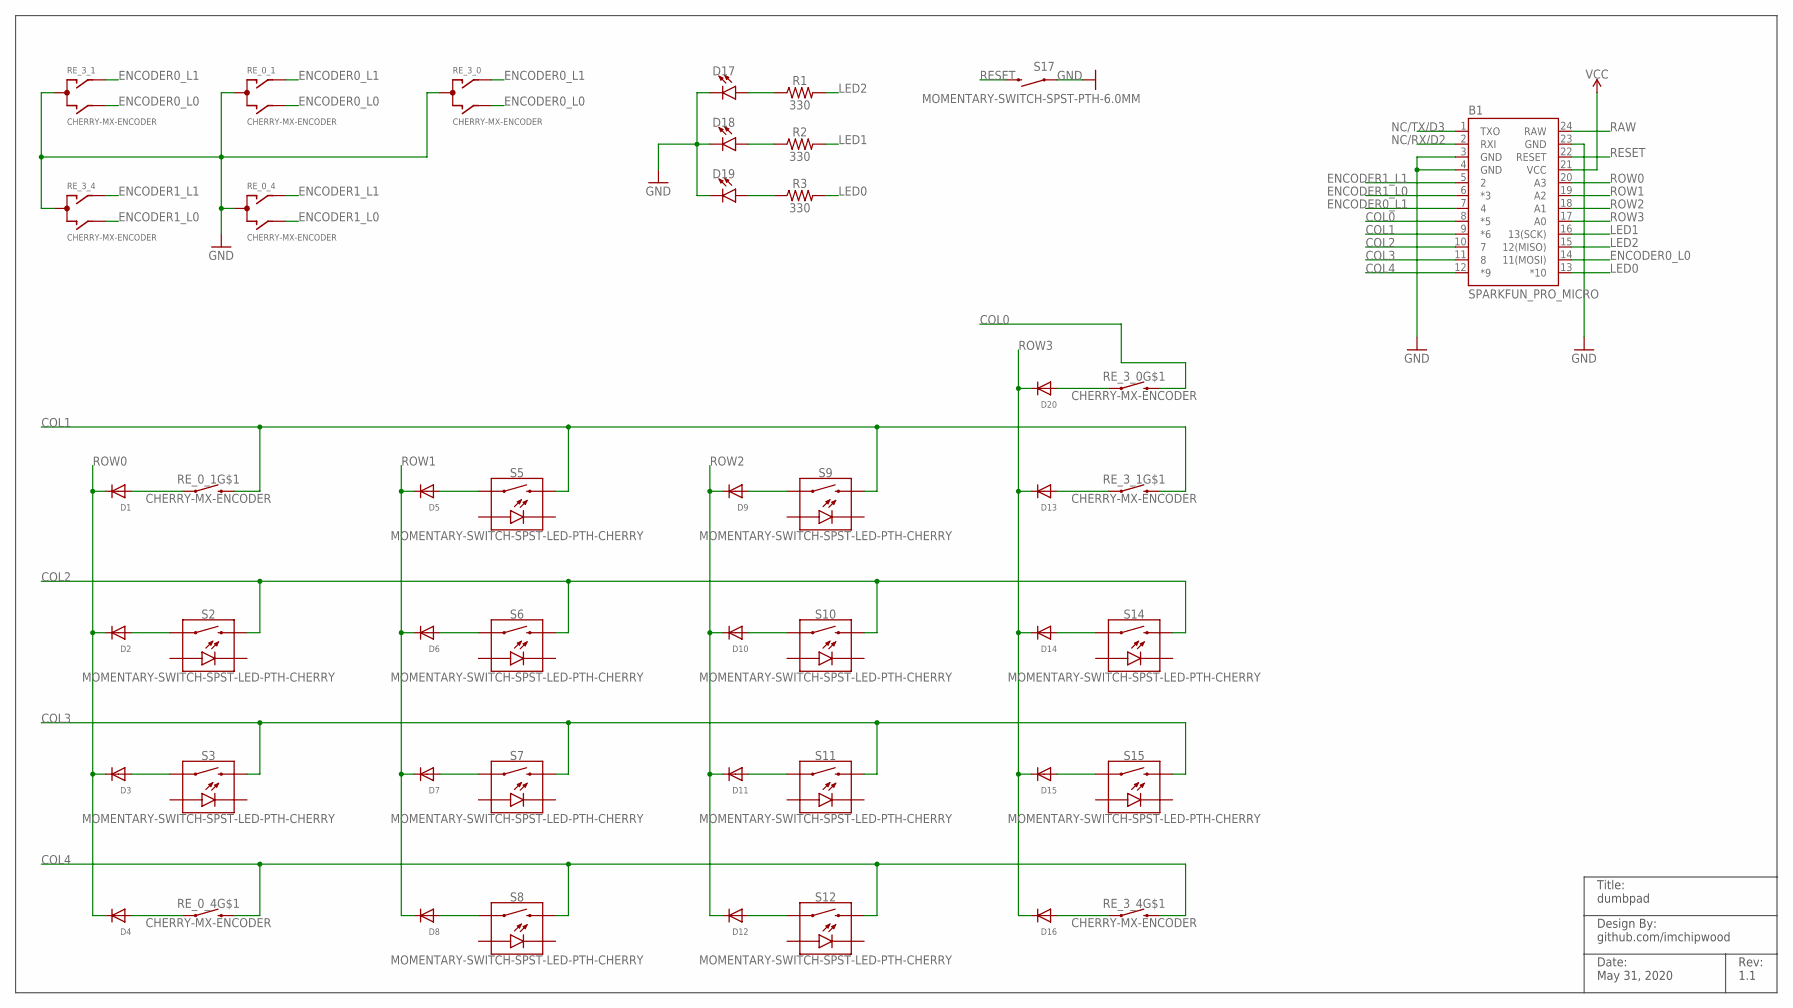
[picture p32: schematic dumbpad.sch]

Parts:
B1: SPARKFUN_PRO_MICRO
D1, D2, D3, D4, D5, D6, D7, D8, D9, D10, D11, D12, D13, D14, D15, D16, D20: DIODEDO-1N4148; DO-1N4148
D17, D18, D19: LED3MM; LED_3MM
R1, R2, R3: 330; AXIAL-0.3
RE_0_1, RE_0_4, RE_3_0, RE_3_1, RE_3_4: CHERRY-MX-ENCODER
S2, S3, S5, S6, S7, S8, S9, S10, S11, S12, S14, S15: MOMENTARY-SWITCH-SPST-LED-PTH-CHERRY; CHERRY-MX-LED
S17: MOMENTARY-SWITCH-SPST-PTH-6.0MM; TACTILE_SWITCH_PTH_6.0MM

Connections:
COL0: B1.8 (*5), RE_3_0.E (2), RE_3_0.S2 (2)
COL1: B1.9 (*6), RE_0_1.E (2), RE_0_1.S2 (2), RE_3_1.E (2), RE_3_1.S2 (2), S5.S2 (2), S9.S2 (2)
COL2: B1.10 (7), S2.S2 (2), S6.S2 (2), S10.S2 (2), S14.S2 (2)
COL3: B1.11 (8), S3.S2 (2), S7.S2 (2), S11.S2 (2), S15.S2 (2)
COL4: B1.12 (*9), RE_0_4.E (2), RE_0_4.S2 (2), RE_3_4.E (2), RE_3_4.S2 (2), S8.S2 (2), S12.S2 (2)
ENCODER0_L0: B1.14 (11(MOSI)), RE_0_1.B, RE_3_0.B, RE_3_1.B
ENCODER0_L1: B1.7 (4), RE_0_1.A, RE_3_0.A, RE_3_1.A
ENCODER1_L0: B1.6 (*3), RE_0_4.B, RE_3_4.B
ENCODER1_L1: B1.5 (2), RE_0_4.A, RE_3_4.A
GND: B1.3 (GND), B1.4 (GND), B1.23 (GND), D17.K (C), D18.K (C), D19.K (C), RE_0_1.C, RE_0_4.C, RE_3_0.C, RE_3_1.C, RE_3_4.C, S17.1
LED0: B1.13 (*10), R3.P$2 (2)
LED1: B1.16 (13(SCK)), R2.P$2 (2)
LED2: B1.15 (12(MISO)), R1.P$2 (2)
unnamed: D4.A, RE_0_4.D (1), RE_0_4.S1 (1)
unnamed: D3.A, S3.S1 (1)
unnamed: D2.A, S2.S1 (1)
unnamed: D1.A, RE_0_1.D (1), RE_0_1.S1 (1)
unnamed: D17.A, R1.P$1 (1)
unnamed: D8.A, S8.S1 (1)
unnamed: D7.A, S7.S1 (1)
unnamed: D6.A, S6.S1 (1)
unnamed: D5.A, S5.S1 (1)
unnamed: D18.A, R2.P$1 (1)
unnamed: D16.A, RE_3_4.D (1), RE_3_4.S1 (1)
unnamed: D15.A, S15.S1 (1)
unnamed: D14.A, S14.S1 (1)
unnamed: D13.A, RE_3_1.D (1), RE_3_1.S1 (1)
unnamed: D19.A, R3.P$1 (1)
unnamed: D12.A, S12.S1 (1)
unnamed: D11.A, S11.S1 (1)
unnamed: D10.A, S10.S1 (1)
unnamed: D9.A, S9.S1 (1)
unnamed: D20.A, RE_3_0.D (1), RE_3_0.S1 (1)
NC/RX/D2: B1.2 (RXI)
NC/TX/D3: B1.1 (TXO)
RAW: B1.24 (RAW)
RESET: B1.22 (RESET), S17.3 (2)
ROW0: B1.20 (A3), D1.C, D2.C, D3.C, D4.C
ROW1: B1.19 (A2), D5.C, D6.C, D7.C, D8.C
ROW2: B1.18 (A1), D9.C, D10.C, D11.C, D12.C
ROW3: B1.17 (A0), D13.C, D14.C, D15.C, D16.C, D20.C
VCC: B1.21 (VCC)

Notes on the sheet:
Rev: 1.1
Date: May 31, 2020
Design By: github.com/imchipwood
Title: dumbpad

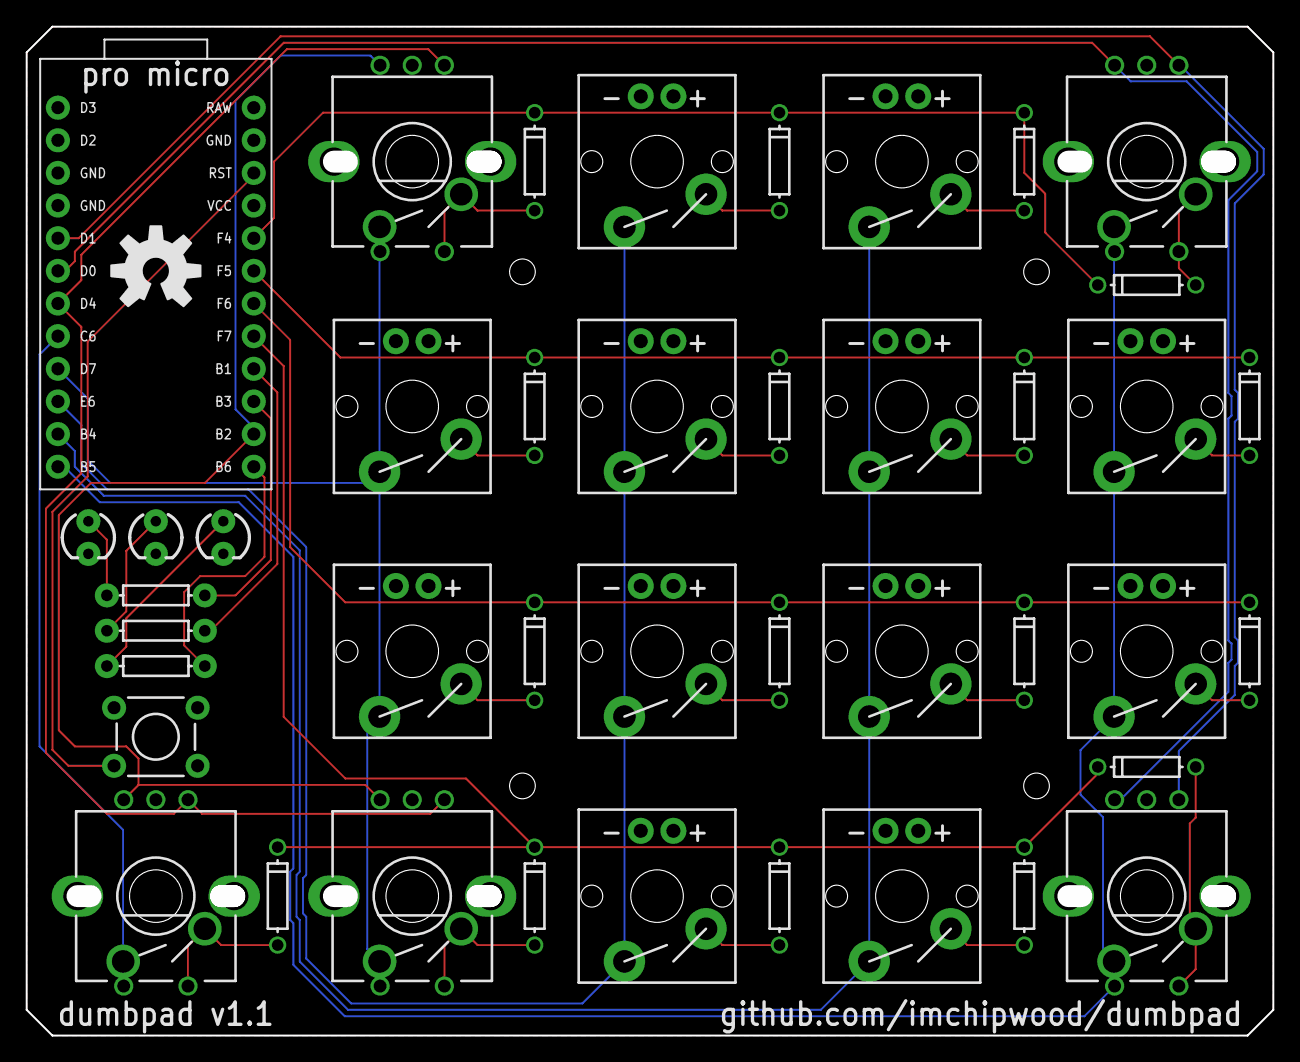
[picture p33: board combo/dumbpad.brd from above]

Board: 2 copper layers, 97.0 x 78.5 mm, 44 parts (1 on the bottom side), 38 nets.

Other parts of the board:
LOGO1, LOGO2: OSHW-LOGOL; OSHW-LOGO-L

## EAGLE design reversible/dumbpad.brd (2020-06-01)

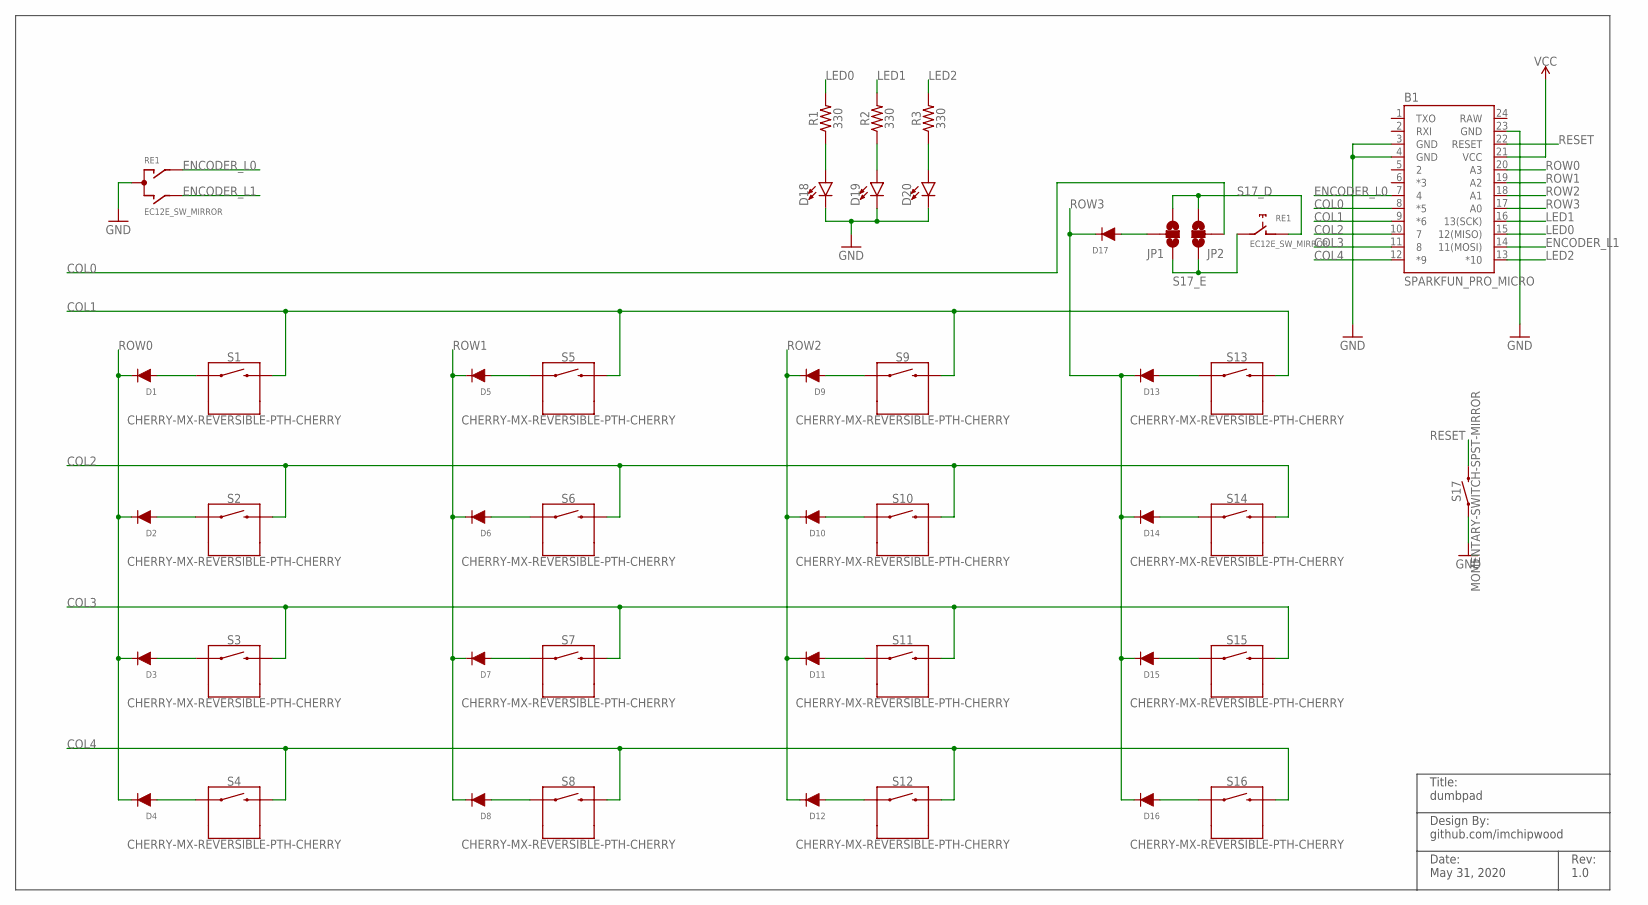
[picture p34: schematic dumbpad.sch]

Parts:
B1: SPARKFUN_PRO_MICRO
D1, D2, D3, D4, D5, D6, D7, D8, D9, D10, D11, D12, D13, D14, D15, D16, D17: DO-1N4148_MIRROR
D18, D19, D20: LED3MM; LED_3MM
JP1, JP2: JUMPER-SMT_3_NO_NO_SILK; SMT-JUMPER_3_0-NO_TRACE_NO-SILK
R1, R2, R3: 330; AXIAL-0.3_MIRROR
RE1: EC12E_SW_MIRROR; ALPS_EC12E_SW_MIRROR
S1, S2, S3, S4, S5, S6, S7, S8, S9, S10, S11, S12, S13, S14, S15, S16: CHERRY-MX-REVERSIBLE-PTH-CHERRY; CHERRY-MX-REVERSIBLE
S17: MOMENTARY-SWITCH-SPST-MIRROR; TACTILE_SWITCH_PTH_6.0MM_MIRROR

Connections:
COL0: B1.8 (*5), JP2.2
COL1: B1.9 (*6), S1.S2_0 (2), S1.S2_1 (2), S5.S2_0 (2), S5.S2_1 (2), S9.S2_0 (2), S9.S2_1 (2), S13.S2_0 (2), S13.S2_1 (2)
COL2: B1.10 (7), S2.S2_0 (2), S2.S2_1 (2), S6.S2_0 (2), S6.S2_1 (2), S10.S2_0 (2), S10.S2_1 (2), S14.S2_0 (2), S14.S2_1 (2)
COL3: B1.11 (8), S3.S2_0 (2), S3.S2_1 (2), S7.S2_0 (2), S7.S2_1 (2), S11.S2_0 (2), S11.S2_1 (2), S15.S2_0 (2), S15.S2_1 (2)
COL4: B1.12 (*9), S4.S2_0 (2), S4.S2_1 (2), S8.S2_0 (2), S8.S2_1 (2), S12.S2_0 (2), S12.S2_1 (2), S16.S2_0 (2), S16.S2_1 (2)
ENCODER_L0: B1.7 (4), RE1.A
ENCODER_L1: B1.14 (11(MOSI)), RE1.B
GND: B1.3 (GND), B1.4 (GND), B1.23 (GND), D18.K (C), D19.K (C), D20.K (C), RE1.C, S17.1
LED0: B1.15 (12(MISO)), R1.P$2 (2)
LED1: B1.16 (13(SCK)), R2.P$2 (2)
LED2: B1.13 (*10), R3.P$2 (2)
unnamed: D4.A, S4.S1_0 (1), S4.S1_1 (1)
unnamed: D3.A, S3.S1_0 (1), S3.S1_1 (1)
unnamed: D2.A, S2.S1_0 (1), S2.S1_1 (1)
unnamed: D1.A, S1.S1_0 (1), S1.S1_1 (1)
unnamed: D18.A, R1.P$1 (1)
unnamed: D8.A, S8.S1_0 (1), S8.S1_1 (1)
unnamed: D7.A, S7.S1_0 (1), S7.S1_1 (1)
unnamed: D6.A, S6.S1_0 (1), S6.S1_1 (1)
unnamed: D5.A, S5.S1_0 (1), S5.S1_1 (1)
unnamed: D20.A, R3.P$1 (1)
unnamed: D16.A, S16.S1_0 (1), S16.S1_1 (1)
unnamed: D15.A, S15.S1_0 (1), S15.S1_1 (1)
unnamed: D14.A, S14.S1_0 (1), S14.S1_1 (1)
unnamed: D13.A, S13.S1_0 (1), S13.S1_1 (1)
unnamed: D19.A, R2.P$1 (1)
unnamed: D12.A, S12.S1_0 (1), S12.S1_1 (1)
unnamed: D11.A, S11.S1_0 (1), S11.S1_1 (1)
unnamed: D10.A, S10.S1_0 (1), S10.S1_1 (1)
unnamed: D9.A, S9.S1_0 (1), S9.S1_1 (1)
RAW: B1.24 (RAW)
RESET: B1.22 (RESET), S17.2
ROW0: B1.20 (A3), D1.C, D2.C, D3.C, D4.C
ROW1: B1.19 (A2), D5.C, D6.C, D7.C, D8.C
ROW2: B1.18 (A1), D9.C, D10.C, D11.C, D12.C
ROW3: B1.17 (A0), D13.C, D14.C, D15.C, D16.C, D17.C
ROW3_A: D17.A, JP1.2
S17_D: JP1.1, JP2.3, RE1.D (1)
S17_E: JP1.3, JP2.1, RE1.E (2)
VCC: B1.21 (VCC)

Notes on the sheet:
Rev: 1.0
Date: May 31, 2020
Design By: github.com/imchipwood
Title: dumbpad

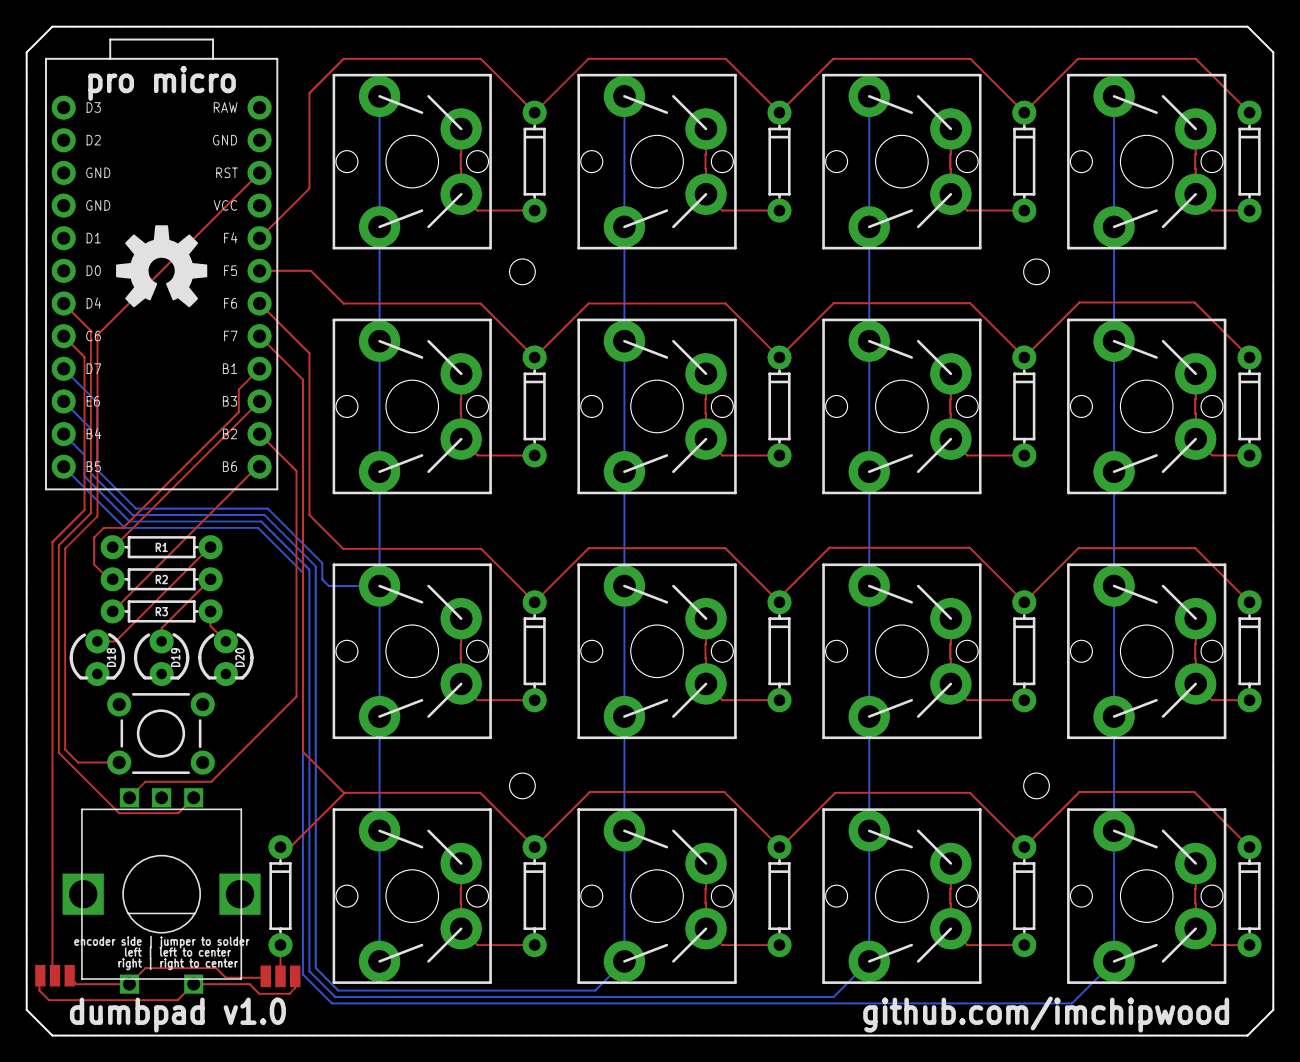
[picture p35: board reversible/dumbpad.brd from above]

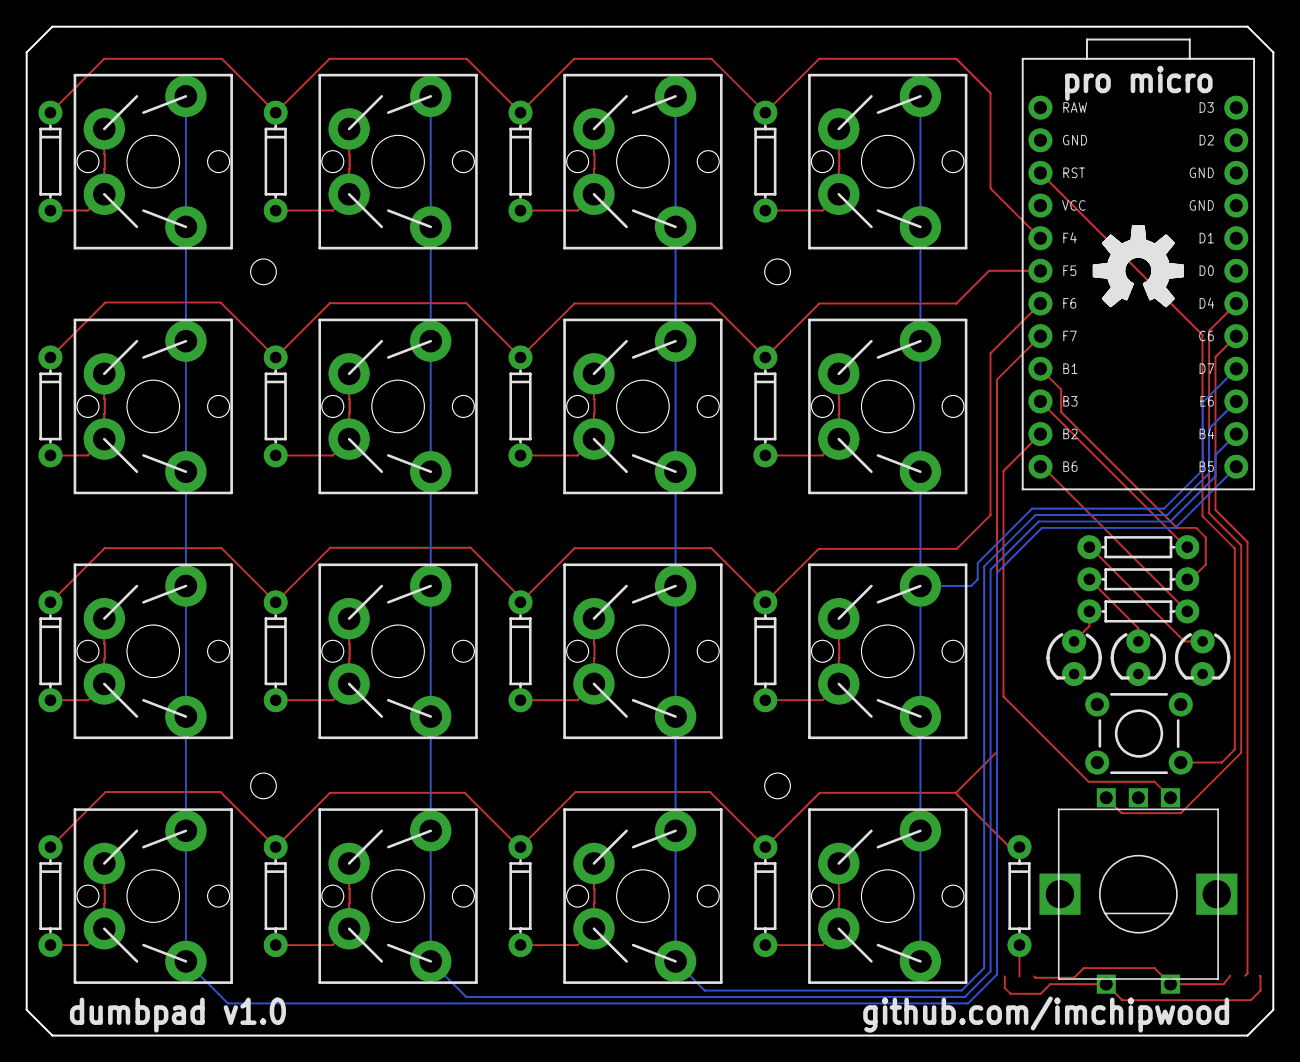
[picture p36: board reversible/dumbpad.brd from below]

Board: 2 copper layers, 97.0 x 78.5 mm, 47 parts (2 on the bottom side), 38 nets.

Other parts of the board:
LOGO1, LOGO2, LOGO3: OSHW-LOGOL; OSHW-LOGO-L

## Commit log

2019-07-14 moved email/name thing
    [dumbpad.brd]
2019-07-14 added reset button, centered diodes on switches
    [dumbpad.brd, dumbpad.sch]
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2019-07-14 minor tweaks, sch as png
    [dumbpad.brd, dumbpad.sch]
2019-07-14 name/contact info on both sides, some pro micro pins labeled to ensure it's not mounted incorrectly
    [dumbpad.brd]
2019-07-14 added labels to all pro micro pins
    [dumbpad.brd]
2019-07-14 shrinking, aligning
    [dumbpad.brd]
2019-07-14 removed resistors from rotary encoder, updated readme
    [dumbpad.brd, dumbpad.sch]
2019-07-28 moved all components to top, rerouted
    [dumbpad.brd, dumbpad.sch]
2019-07-28 slight tweaks to spacing, orientation of one diode, etc.
    [dumbpad.brd]
2019-07-28 v0.4 done - moved diodes to right side of switches for cleaner routing. Adjusted dimension slightly to give more room around switches so keycaps don't hang over the sides
    [dumbpad.brd]
2019-07-28 more tweaks to v4 for A E S T H E T I C
    [dumbpad.brd]
2019-07-29 who doesn't like LEDs
    [dumbpad.brd, dumbpad.sch]
2019-08-03 final touches to v0.5
    [dumbpad.brd, dumbpad.sch]
2019-08-03 updated readme for v0.5 - 2x LEDs, 2x resistors
2019-08-04 added Open Source Hardware logo to tplace and bplace
    [dumbpad.brd, dumbpad.sch]
2019-08-04 added screenshot of layout and put it in the readme
    [dumbpad.brd]
2019-08-04 removed top OSHW silk, adding reset button back shortly
    [dumbpad.brd]
2019-08-04 added reset button back to v0.5
    [dumbpad.brd, dumbpad.sch]
2019-08-04 minor tweak to routing
    [dumbpad.brd]
2019-08-30 dual encoders on the bottom, need to add mirror switches
    [dumbpad.brd, dumbpad.sch]
2019-08-30 merging v05 into master manually
    [dumbpad.brd, dumbpad.sch]
2019-08-30 using reversible sockets
    [dumbpad.brd, dumbpad.sch]
2020-03-20 added dual-encoder image from someone who actually made one
2020-04-11 added jumpers for reversing encoder when using encoder on right side instead of left
    [dumbpad.brd, dumbpad.sch]
2020-04-11 updated revision to v0.7
    [dumbpad.brd, dumbpad.sch]
2020-04-12 merging v08_jumpers to master
    [dumbpad.brd, dumbpad.sch]
2020-04-15 moved some wires to avoid sketchy tolerances and updated readme
    [dumbpad.brd]
2020-04-22 added 3rd LED for numlock indication
    [dumbpad.brd, dumbpad.sch]
2020-04-24 moved LEDs, added more gs
    [dumbpad.brd, dumbpad.sch]
2020-04-24 made reversible sockets show outline on tplace and bplace
    [dumbpad.brd, dumbpad.sch]
2020-04-29 updated readme, made jumpers a little bigger for easier soldering, updated version to 1.0
    [dumbpad.brd, dumbpad.sch]
2020-05-02 swapped some LED pins to make the first two LEDs connecting to the same pins as v0.x PCBs
    [dumbpad.brd, dumbpad.sch]
2020-05-06 all parts have bottom silk screen now, rerouted some stuff
    [dumbpad.brd, dumbpad.sch]
2020-05-06 added mounting holes
    [dumbpad.brd]
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2020-05-06 fixed issue with wrong jumper size
    [dumbpad.brd, dumbpad.sch]
2020-05-07 v1.0 dual encoder version with debug headers
    [dumbpad.brd, dumbpad.sch]
2020-05-17 non-debug version of dualencoder layout
    [dumbpad.brd, dumbpad.sch]
2020-05-17 minor tweaks
    [dumbpad.brd]
2020-05-17 changed mounting holes to 40mm square
    [dumbpad.brd]
2020-05-17 changed mounting holes to 40mm
    [dumbpad.brd]
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2020-05-21 dualencoder now has cherry/encoder sockets for putting encoders on either top row or bottom row
    [dumbpad.brd, dumbpad.sch]
2020-05-21 dual + single encoder configuration
    [dumbpad.brd, dumbpad.sch]
2020-05-21 updating board and adding cam file
    [dumbpad.brd]
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2020-05-21 minor changes
    [dumbpad.brd, dumbpad.sch]
2020-05-22 long pads with mill
    [dumbpad.brd, dumbpad.sch]
2020-05-22 rerouted some stuff
    [dumbpad.brd]
2020-05-22 organized schematic, silkscreen tweaks,
    [dumbpad.brd, dumbpad.sch]
2020-05-22 rerouted and moved things around, updated readme
    [dumbpad.brd]
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2020-05-30 adding gerbers, got slots working, updated readme
    [dumbpad.brd, dumbpad.sch]
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2020-05-31 master now contains all variations of the board, organized into their own folders
    [dumbpad.brd, dumbpad.sch]
2020-06-01 updated library for combo_teensy
    [dumbpad.brd, dumbpad.sch]
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2020-06-01 fixing bad merge
    [dumbpad.brd, dumbpad.sch]
2020-06-01 fixing naming issue in combo
    [dumbpad.brd, dumbpad.sch]
2020-06-01 matching reversible version encoder pins to combo
    [dumbpad.brd, dumbpad.sch]
2020-06-01 fixed encoder pin naming mismatch, updated screenshot
    [dumbpad.brd, dumbpad.sch]
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2021-04-01 copying initial case files from other repo
    [dumbpad_case.skp, dumbpad_case_attempt002.stl]
2021-04-01 updated case to have slight relief for usb cable
    [dumbpad_case.skp, dumbpad_case.stl]
2021-04-02 adding embossed version
    [dumbpad_case.skp, dumbpad_case_emboss.skp, dumbpad_case_emboss.stl]
2021-04-04 updated usb port relief area
    [dumbpad_case.skp, dumbpad_case.stl, dumbpad_case_emboss.skp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]
2021-04-04 updated readme, removed unused stl
    [dumbpad_case_attempt002.stl]
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2021-09-22 added plate stl files & plate readme
    [dumbpad_2rotary.stl, dumbpad_no_rotary.stl, dumbpad_single_rotary.stl]
2021-09-22 added stl files and readme for plates
    [2_bot.stl, 2_top.stl, bot_left.stl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]
2021-09-23 updated plate thickness
    [2_bot.stl, 2_top.stl, bot_left.stl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]
2022-01-22 convert from Eagle to KiCad and replaced LEDs for OLED Display
    [dumbpad.kicad_sch]
2022-02-09 Dumbpad with RGB and Hotswap
    [dumbpad.kicad_pcb, dumbpad.kicad_sch]
2022-02-09 v3.x: Add Gerberfiles
    [dumbpad.kicad_pcb]
2022-04-28 fix schematic and remove missing drawing sheet
    [dumbpad.kicad_sch]
2022-04-29 add missing mounting holes from the conversion
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2022-05-23 Fix link to full plate stl
2023-01-31 Fixed spelling on line 44
    Line 44 had the spelling baord, fixed it to board
2024-05-21 added note regarding non-plated through-holes
    ... which will potentially throw red flags for manufacturers
2024-06-19 Added new case designs
    [6mm_split_shaft_pot_knob_12mm.stl, dumb_pleyt_v2.stl, dumbpad_case_v2.stl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]
2026-03-03 Added images for completed keypad v1.3.1
    [dumbpad.kicad_pcb]

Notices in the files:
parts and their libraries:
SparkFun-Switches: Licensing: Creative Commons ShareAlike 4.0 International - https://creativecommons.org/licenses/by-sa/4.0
